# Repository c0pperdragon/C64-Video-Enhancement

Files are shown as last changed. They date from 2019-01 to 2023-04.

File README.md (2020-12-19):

# C64 Video Enhancement

FPGA based modification board for the Commodore 64 computer to produce YPbPr or RGB video output.

The C64 is the most iconic device of the 8-bit computer era and there is a huge library of
software and hardware modifications available.
Nevertheless the video output quality is inherently poor by modern standards, even with the use
of the s-video option. This is specially true with LCD flat screens that amplify the 
visual artifacts even more.

The biggest problem here is the fact, that the VIC-II video chip directly creates a
chrominance signal in the weird and strange way that is necessary for use with
analog television systems. It is then basically impossible to truly convert it back to 
any form of RGB or other component signal (and I tried really, really hard).
And even the luminance signal of the VIC-II is far from perfect and carries a lot of
noise from various sources.

So the way to go was then to bypass the chrominance/luminance signal generation of the VIC-II
and make a solution that computes a YPbPr signal directly from the digital information available
inside the computer. 
As it turns out, it is enough to passively listen to just about 22 pins of the VIC-II to figure out what 
video signal it actually intends to generate. Using the information from these pins and some
logic implemented in an FPGA, a pixel-perfect replication of the video image can be generated.

## Hardware

This mod evolved from a previous version that uses my generic 
[A-Video board](https://github.com/c0pperdragon/A-VideoBoard/tree/master/c64mod). 
It fixes the main
shortcomings of this version, as it was a very ugly install and it needed big holes in the case
for the three RCA plugs. It is compatible with the VIC-II adapter board and the firmware.
This board now is designed to replace the RF modulator and use the existing holes in the 
case. No need to modify the outside of the C64 in any way.

The mod set consists of two main parts:  
* VIC-II adapter
    This is installed between the existing VIC-II and its socket and sniffs all relevant
	signals and translates them to 3.3V logic levels for use by the FPGA.
* FPGA board
    This is connected via a ribbon cable to the adapter to receive the signal stream and
	provide a YPbPr output signal on a 4-pin TRRS jack. 
	Additionally this board carries the necessary electronics to take over the functions 
	of the removed RF modulator to amplify the composite and s-video signals (so the original A/V-jack 
	is still functional).
	
Installation on a 'short' main board	
	
## Compatibility

The mod is intended to eventually support all revisions of the C64: PAL and NTSC, 
long boards and short boards and 5V or 12V supply voltage.
The hardware is already compatible (tested with a long 12V-board and a short 5V-board).
but for some variants of the VIC-II (specifically the 6567R56A that was used in the very
first devices) you may need to update the firmware to the latest version.
The mod boards as sold by videogamesperfection.com have the firmware version 2.6 which already
works with most variants of the VIC. 

To support the 6567R56A chip, the mod additionally needs to be jumpered because it can not auto-detect
this specific variant on its own: You need to connect pin 5 of the JTAG header to ground. This can fairly easily be done by
connecting it to pin 2 of this header.

## Video output

The mod board generates a YPbPr signal which can be switched to one of three modes using the onboard slider switch
(right to left, when looking at the switch):
* 240p/288p progressive 60Hz/50Hz
* 480p/576p progressive 60Hz/50Hz using scanline doubling
* 480p/576p progressive 60Hz/50Hz with visual scanline effect

The signal is provided on a 4-pin TRRS-jack. The order of signals (tip to sleve) is as follows:  Y, Pb, Pr, GND.
This assignment seems to be a kind of standard, but you can use any breakout cable that converts TRRS to 3 RCA 
jacks, as long as the common GND is located at the sleeve.

Use the three-state switch at the back to select the video mode. The 240p/288p mode is not supported by all TVs and will
probably create some de-interlacing artefacts. On the other hand, this mode is perfect to feed into a dedicated
upscaler that can handle it (the famous 'Framemeister' or the 'OSSC' come to mind).
The 480p/576p modes are best used with TVs and give quite a good picture already without any additional upscaler.

Output mode with visual scanline effect	

## Installation instructions

### Adapter board

* Remove the VIC-II and put the adapter board into the socket. The correct orientation for the
adapter is such that the ribbon cable either extends to the right or to the top (depending on your main board).
On some main boards, this could require to either relocate some 
passives or to insert an additional IC-socket to rise the adapter above these passives. 
* Put the VIC-II into the adapter. Make sure to put it in the original orientation.
* I have found that some boards have such a low-quality IC socket that it will not hold the adapter board tightly enough. 
If this is the case, you should replace it with a precision IC socket.
 
### Test the FPGA board (optional)

Before de-soldering the RF modulator, you can test the function of the main mod board. For this, temporarily connect 
one of GND3,GND4,GND5 somewhere to the C64 GND and the rightmost hole of RFCON2 to +5V. Connect the ribbon cable from the
adapter to the FPGA board. The TRRS plug should then already output a proper YPbPr signal.

### Install the FPGA board permanently

* Remove the RF modulator and remove all the solder from the pin holes.
* Install both 4-pin headers in the mainboard, pointing upwards. These pins will later go into the FPGA board to provide power
and to carry the analog signals in and out (to replicate the functionality of the RF modulator).
* Check into which holes in the FPGA board these pins will go. For installation on a "long" main board, these are the
8 holes at the edge, for a "short" main board, use the other set of holes.
* Temporarily stick the FPGA board onto the pins and use it as a means to align the remaining pins correctly to the main board
(either two pins on each side if installed on a 'long' board or only two pins at the back if installed on a 'short' board) 
and solder them to the main board, also pointing upwards. 
These pins are needed to connect the GND as well as to provide the correct vertical spacing.
* Align the FPGA board vertically to the holes in the computer case and solder all pins. For standard pins this
normally means to rise the FPGA board all the way up to the very tip of these pins. 
* If your VIC-II uses the higher voltage (all 6xxx - variants), you need to short the JPLUM1 solder bridge. 
* Connect the 20-pin ribbon cable to the FPGA board.

### Cabling

The 4-pin TRRS connector provides the YPbPr signal, and this can be connected to a TV or upscaler using different cabling options:
* A breakout adapter with a TRRS jack and 3 female RCA jacks. With this a standard YPbPr cable with male plugs can be attached.
* A cable with a TRRS jack and 3 male RCA plugs. This can be plugged directly into the YPbPr input on a TV.
* Some TVs also use a TRRS jack to input YPbPr, probably to safe cost and space. There it is possible to directly use a cable 
with two TRRS plugs on both sides (given that the TV uses the same pin assignment: Tip=Y, Ring 1=Pb, Ring 2=Pr, Sleeve=GND).

## Create your own kit
Everything to create the RF replacement board as well as the VIC adapter board (see the 
[A-Video board](https://github.com/c0pperdragon/A-VideoBoard/tree/master/c64mod)
repository) is completely open source and free to use for any purpose. 

Most parts are pretty standard, only the TRRS connector and the three-way switch are probably not that easy to source with
every electronics retailer.
For your convenience, I have set up a 
[BOM](doc/fpgaboard_bom.ods)
and a project parts list at 
[mouser](https://www.mouser.com/ProjectManager/ProjectDetail.aspx?AccessID=9f8979b031)
that contains everything besides the TRRS jack. For this jack you can use a "Cliff FC68125" with is available at 
several retailers or another part with the same footprint. 
For my original design I myself used an 
[unbranded part from a local retailer](https://www.conrad.at/de/p/conrad-components-klinken-steckverbinder-3-5-mm-buchse-einbau-horizontal-polzahl-4-stereo-schwarz-1-st-718732.html)
which did meet all my requirements and was pretty cheap as well.

Hint for assembling: The holes denoted GND1 - GND5 should not be populated with pin headers during assembly. It is intended that
pin headers that are installed into the C64 main board will stick up through the holes and are soldered as last step
of the installation.
Hint for testing: After the board is assembled and before installing it into the computer, you can already upload
a test pattern generator to the FPGA (available as binary release in the 
[A-Video project](https://github.com/c0pperdragon/A-VideoBoard/releases). 
Do this with a USB-Blaster connected to the JTAG headers. You also must provide 5V-9V on the power pin
(the rightmost hole of RFCON2 - as seen from the edge of the board) and 0V to any of GND3, GND4, GND5.  
The test pattern should show some fancy colors and three gradients to test each of the three signal components.
If the gradients look uneven or have less than 32 different steps each, you probably have some soldering 
problems in the resistor networks.

## Color palette
I have chosen very bright colors for the video output, to give the picture a fresher look. 
Especially "Mayhem in Monsterland" makes much more sense this way ;-)
I know that these saturated colors may not be to everybodies taste. If you want to reduce the color
saturation as a whole, you can replace the resistors R18 and R19 with lower values. 75 Ohm works fine, or
68 Ohm for even lower saturation. If you don't want to desolder these small parts, you could as
well solder an additional 150 Ohm right on top of each of the existing R18 and R19 (this also results
in 75 Ohm total). 

Beginning with firmware version 2.0, you have the possibility to freely choose a color palette that
suits your taste. It is even possible to reporgram the color signals to produce RGsB or RGB signals instead
of YPbPr. When you choose to disable sync, you need to get the sync signal from the original A/V port instead.
In this case it is even possible to build an adapter cable that joins the A/V signals and the RGB signals
together to a single SCART connector.

When you want to use a color palette according to the "colodore" algorithm, you can use Hojo-Norem's
[palette tuning program](https://github.com/Hojo-Norem/c0pperdragon-VIC-II-Palette-editor). 

## Details on color signal reprogramming
Beginning with firmware 2.0, the mod uses a set of 256 16-bit registers to hold the palette information.
These registers can be reprogrammed directly from the C64 and stored persistenly on the FPGA chip.
#### Unlock the registers
Before you can change the register contents, you need to write a value of 137 to memory address 53311.
Then switch the output mode switch to a different mode and back again (back is optional). This sequence is 
necessary to prevent untrusted code to modify the settings. This could a be a special concern on demo competitions.
#### Write into registers
For writing a 16-bit value, you need to first write the low byte into address 53308 and the high byte
into address 53309. Then write the target register number into address 53310. You can store the same value
into multiple registers by writing additional register numbers into 53310 without changing the data each time.
Note that it is not possible to read out any register contents. 
#### Store permanently
When you have changed the registers to your liking, you can store this permanently by writing the value 138
to address 53311. During storing this will also cause some random pixels to appear on the screen for a short time. 
#### Meaning of the registers
The registers can be thought of to form a 16x16 matrix (stored line by line), where each cell specifies the exact color
that needs to be produced when the computer wants to display one of its 16 colors, with the consideration
of which color has been displayed in the line directly above. 

If you do not want to simulate PAL color blending, all rows in the matrix will hold the same value. 
There it does not matter for the current line which color has been displayed above. 

If you want to do color blending, you can cook up any coloring blending 
scheme you want. The register accessed is always defined by currentcolor * 16 + colorabove. 

Each register contains 3 5-bit numbers that specifiy the analog signal levels to be sent on the signal outputs.

| Bits  | Signal |
| ----- | --- |
| 0-4 | Pr |
| 5-9 | Pb |
| 10-14 | Y |
| 15 | unused |

#### Disabling sync 
Bit 15 of register 0 has a special function, as it can be used to suppress the sync signal.
Writing a 1 into this bit will turn off sync on the Y line, whenever the 240p/288p output mode is selected.
In this mode, the luminousity line of the original A/V connector can be used to get the sync signal from
instead. 

## Pixel clock generation

Some C64s - especially the very first models - have a very bad clock circuit that generates an unstable and shaky pixel clock. 
This may lead to all sorts of stability problems, including the component mod showing sparkly pixels or worse effects. 
Because of this, I have added a hidden feature into the FPGA board that generates a stable clock signal you can
use instead. For more details on how to wire this all up, you can check the various issue threads on this topic (but be aware that
this is getting very technical very fast).

## Contact
For technical questions and also to share your experience with this modification, please
use the issue tracking system of github. 

If you really insist on donating money, please feel free to send any amount to my paypal account: 
reinhard.grafl (at) aon.at

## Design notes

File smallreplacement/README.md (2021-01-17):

# Small RF Replacement

I made a smaller variant of the RF replacement board that can be used in C128 machines as well 
as in the C64C. By not supporting the "long" C64 boards with their 12V VIC, this FPGA board could be made
as small as the smaller variant of the RF modulator and this should now also fit where the original
board was too large.

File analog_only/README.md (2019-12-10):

# C64 Video Enhancement, Analog Only

The analog circuit that was just meant as a simple replacement to take over
the function of the RF modulator to keep the A/V port somehow functional,
seems to be remarkably good in its own right.
So for users that just want a cheap solution to improve the original
video signals (luma,chroma,composite), this board may be a viable option.

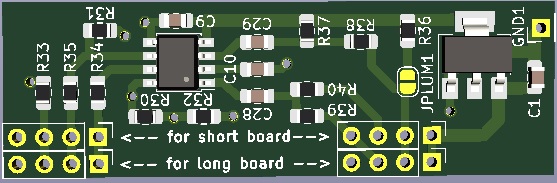
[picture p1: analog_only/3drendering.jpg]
3D rendering of the board


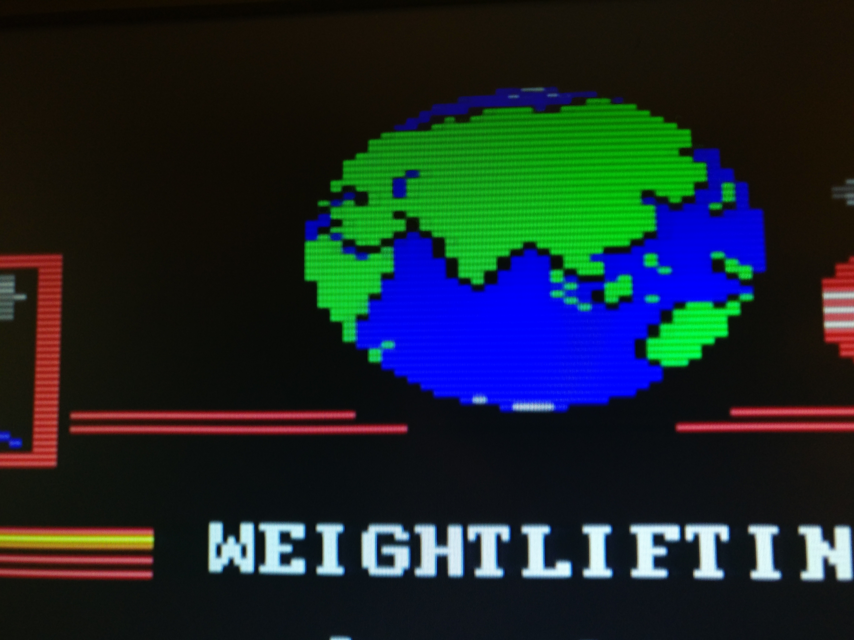
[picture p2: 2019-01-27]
doc/worldgames.jpg

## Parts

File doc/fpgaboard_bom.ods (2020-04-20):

Manufacturer | Manufacturer Number | Designator | Qty | Description | Case | SMD/ TH | PCB side | Comments
Intel | 10M02SCE144C8G | U2 | 1 | FPGA - Field Programmable Gate Array, | 144EQFP | SMD | Top | When hand-soldering: Solder center pad from bottom side
Texas Instruments | THS7316DR | AMP1,AMP2 | 2 | Video Amplifiers 3-Ch HDTV Video Amp | SOIC-8 | SMD | Top
Texas Instruments | LM1117IMPX-3.3/NOPB | REG1,REG2 | 2 | LDO Voltage Regulators 800MA LDO LINEAR REG | SOT-223-4 | SMD | Top
IQD Frequency Products | LFSPXO024957Reel | OSC1 | 1 | Standard Clock Oscillators 25MHz 3.3V 50ppm -40C +85C | 5 mm x 3.2 mm | SMD | Top
NKK Switches | SS14MDH2 | SW1 | 1 | Slide Switches SP3T ON-ON-ON |  | TH | Top
Cliff | FC68125 | J1 | 1 | TRRS Jack |  | TH | Top
any |  | L1,L2,L3 | 3 | Fixed inductors 10uH, 20% | 2012 | SMD | Top
any |  | C8 | 1 | Aluminium Electrolytic Capacitor 100uF 16V | 6.3 mm diameter | SMD | Top
any |  | C1,C2,C3,C4,C5,C9,C30 | 7 | Ceramic capacitor 10uF, 16V, 20% | 2012 | SMD | Top
any |  | C10,C28,C29 | 3 | Ceramic capacitor 100nF, 16V, 20% | 1608 | SMD | Top
any |  | C6,C7 | 2 | Ceramic capacitor 100nF, 16V, 20% | 1608 | SMD | Top/Bottom | Bottom until Rev.3, Top from Rev.4 on
any |  | C11-C27,C31-C34 | 21 | Ceramic capacitor 100nF, 16V, 20% | 1608 | SMD | Bottom
any |  | R27,R28,R29,R33,R34,R35 | 6 | Thick film resistor, 75 Ohm, 1% | 2012 | SMD | Top
any |  | R17,R18,R19 | 3 | Thick film resistor, 150 Ohm, 1% | 2012 | SMD | Top
any |  | R37,R40 | 2 | Thick film resistor, 330 Ohm, 1% | 2012 | SMD | Top
any |  | R36,R38,R39 | 3 | Thick film resistor, 680 Ohm, 1% | 2012 | SMD | Top
any |  | R2,R7,R12,R31 | 4 | Thick film resistor, 1k Ohm, 1% | 2012 | SMD | Top
any |  | R1 | 1 | Thick film resistor, 1.1k Ohm, 1% | 2012 | SMD | Top
any |  | R3,R8,R13 | 3 | Thick film resistor, 2k Ohm, 1% | 2012 | SMD | Top
any |  | R32 | 1 | Thick film resistor, 2.2k Ohm, 1% | 2012 | SMD | Top
any |  | R30 | 1 | Thick film resistor, 3.3k Ohm, 1% | 2012 | SMD | Top
any |  | R4,R9,R14 | 3 | Thick film resistor, 4.02k Ohm, 1% | 2012 | SMD | Top
any |  | R5,R10,R15 | 3 | Thick film resistor, 8.06k Ohm, 1% | 2012 | SMD | Top
any |  | R6,R11,R16 | 3 | Thick film resistor, 16k Ohm, 1% | 2012 | SMD | Top
any |  | R20-R26 | 7 | Thick film resistor, 10k Ohm, 1% | 2012 | SMD | Top
any |  | GPIO1 | 1 | Standard pin header, 2x10 pins, 2.54mm , gold plated |  | TH | Top
any |  | JTAG1 | 1 | Standard pin header, 2x5 pins, 2.54mm, gold plated |  | TH | Top

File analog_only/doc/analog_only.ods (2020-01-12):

Manufacturer | Manufacturer Number | Designator | Qty | Description | Case | SMD/ TH | PCB side | Comments
Texas Instruments | THS7316DR | AMP2 | 1 | Video Amplifiers 3-Ch HDTV Video Amp | SOIC-8 | SMD | Top
Texas Instruments | LM1117IMPX-3.3/NOPB | REG2 | 1 | LDO Voltage Regulators 800MA LDO LINEAR REG | SOT-223-4 | SMD | Top
any |  | C1,C9 | 2 | Ceramic capacitor 10uF, 16V, 20% | 2012 | SMD | Top
any |  | C10,C28,C29 | 3 | Ceramic capacitor 100nF, 16V, 20% | 2012 | SMD | Top
any |  | R33,R34,R35 | 3 | Thick film resistor, 75 Ohm, 1% | 2012 | SMD | Top
any |  | R37,R40 | 2 | Thick film resistor, 330 Ohm, 1% | 2012 | SMD | Top
any |  | R36,R38,R39 | 3 | Thick film resistor, 680 Ohm, 1% | 2012 | SMD | Top
any |  | R31 | 1 | Thick film resistor, 1k Ohm, 1% | 2012 | SMD | Top
any |  | R32 | 1 | Thick film resistor, 2.2k Ohm, 1% | 2012 | SMD | Top
any |  | R30 | 1 | Thick film resistor, 3.3k Ohm, 1% | 2012 | SMD | Top

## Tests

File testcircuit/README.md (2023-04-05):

# Test device for the C64 video enhancement mod

In case of a series production of the mod, you probably need some means
to test the mod boards without actually installing them into a real C64.
For this purpose, the necessary input signals can be generated by a 
second FPGA board, programmed to simulate the various VIC signals.
These are fed into the VIC adapter board (via a ZIF socket for example)
which will in turn drive the FPGA board under test to generate the test image.

The provided firmware (TestSignalGenerator.pof) will turn a standard 
C64 video enhanchement board  into a signal generator that uses the GPIO1 port 
and two additional pins as outputs instead of inputs.
Be careful to use such a board only for this test purpose, as
it will cause damage to connect some other signal source to these outputs.

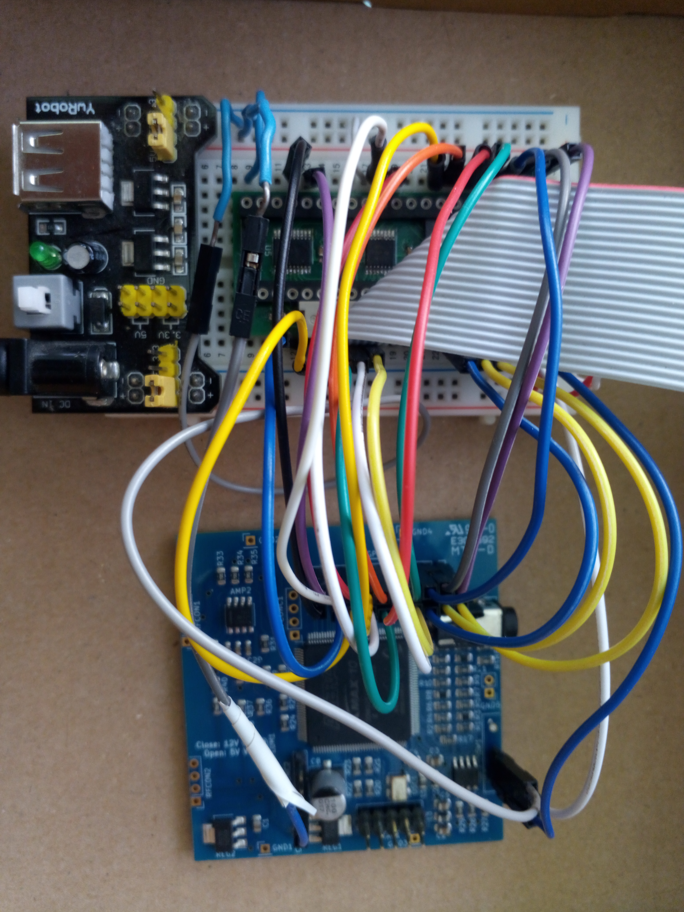
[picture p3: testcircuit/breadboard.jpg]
Experimental setup using a breadboard
	

## Wiring the power 

| Power input  | Signal generator | VIC adapter | VIC-IIe adapter |
| --- | --- | --- | --- |
| +5V | RFCONC2 1 | Pin 40 | Pin 48 |
| GND | SW1 3 | Pin 20 | Pin 24 |

## Wiring up the signal generator outputs to the VIC adapter

| FPGA pin | Signal generator | VIC adapter  | VIC-IIe adapter | VICIIdizer | Signal |
| --- | --- | --- | --- | --- |--- |
| 74 | GPIO1 1 | Pin 1 | Pin 1 | Pin 1 | DB6 |
| 76 | GPIO1 3 | Pin 2 | Pin 2 | Pin 2 | DB5 |
| 78 | GPIO1 5 | Pin 3 | Pin 3 | Pin 3 | DB4 |
| 80 | GPIO1 7 | Pin 4 | Pin 4 | Pin 4 | DB3 |
| 87 | GPIO1 9 | Pin 5 | Pin 5 | Pin 5 | DB2 |
| 91 | GPIO1 11 | Pin 6 | Pin 6 | Pin 6 | DB1 |
| 97 | GPIO1 13 | Pin 7 | Pin 7 | Pin 7 | DB0 |
| 99 | GPIO1 15 | Pin 10 | Pin 13 | Pin 10 | CS |
| 101 | GPIO1 17 | Pin 11 | Pin 14 | Pin 11 | RW |
| - | GND | Pin 12 | Pin 10 | - | BA (unused) |
| 105 | GPIO1 19 | Pin 16 | Pin 12 | Pin 16 | AEC |
| 106 | GPIO1 20 | Pin 17 | Pin 18 | Pin 22 | PHI0/CLK |
| 103 | GPIO1 18 | Pin 24 | Pin 32 | Pin 24 | A0 |
| 100 | GPIO1 16 | Pin 25 | Pin 33 | Pin 25 | A1 |
| 98 | GPIO1 14 | Pin 26 | Pin 34 | Pin 26 | A2 |
| 92 | GPIO1 12 | Pin 27 | Pin 35 | Pin 27 | A3 |
| 88 | GPIO1 10 | Pin 28 | Pin 36 | Pin 28 | A4 |
| 81 | GPIO1 8 | Pin 29 | Pin 37 | Pin 29 | A5 |
| 79 | GPIO1 6 | Pin 35 | Pin 43 | Pin 35 | DB11 |
| 77 | GPIO1 4 | Pin 36 | Pin 44 | Pin 36 | DB10 |
| 75 | GPIO1 2 | Pin 37 | Pin 45 | Pin 37 | DB9 |
| 39 | SW1 1 | Pin 38 | Pin 46 | Pin 38 | DB8 |
| 40 | SW1 2 | Pin 39 | Pin 47 | Pin 39 | DB7 |
| 70 | R0 -> SW1 4 | - | - | Pin 21 | SUBCARRIER  |

_(Most of the pins on both adapters are in the same location relative to pin 1, only the five pins 10-18 are in different locations)_

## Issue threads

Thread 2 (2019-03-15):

Production progress and delivery

c0pperdragon, 2019-03-15:
To keep everybody informed about the situation of my production efforts, I will regularly update this thread.

As you probably guessed, I did not expect such a demand and I did not even have the neccessary parts ready. Of course I now ordered enough to produce 10 kits, and this delivery should arrive in the next days. In the meantime I did scrape together my last pieces and could create just 1 VIC adapter board (which is basically half a kit).

A collegue agreed to let me use his reflow oven and solder paste to speed up a small part of the assembly, namely the underside of the FPGA board. For the rest I still need to manually solder everything. Until we can do that (the solder paste stencil may be a bit tricky to make), I will concentrate on making the adapter boards. So I will not get a complete kit together before at least two weeks or so.

Anyway whenever I have complete kits, I will send them to you in order of payment.
I will send out individual mails notifying you about your position on the list.

Adapter boards: 1  FPGA boards: 0

c0pperdragon, 2019-03-20:
Disaster: My main C64 (a 1986 breadbox) just went to a black screen. This leaves me with only a C64C which I had turned into a NTSC machine for use of making the firmware NTSC compatible.
Anyway this does not hinder me to create and test the actual hardware for the mod, but I can not improve on the firmware features for PAL right now.  With some luck it is a simple fix (the PLA being the first suspect), but I will surely need replacement parts.
Anyway, building of the hardware progresses as planned.

Adapter boards: 3  FPGA boards: 0

bodgit, 2019-03-20:
I found this project via [oshpark.com](https://oshpark.com/). I'm interested in one of these, are orders being taken somewhere? Or have I missed the boat?

Also, would this be feasible to adapt to a C128 (for the 40-column output)?

c0pperdragon, 2019-03-21:
Please leave this issue thread for announcements concerning the current production efforts. You can open any number of new issues for questions.

By the way: Production is progressing just find.
Adapter boards: 5 FPGA boards: 0

c0pperdragon, 2019-03-23:
Busy weekend.
Adapter boards: 10 FPGA boards: 0

c0pperdragon, 2019-03-31:
Building the FPGA boards is a bit more time-consuming than the adapter boards. I finished and tested two this weekend.  But I am not satisfied with the firmware yet, as it still has incompatibilities in the border engine, so I can not ship the kits yet. To get this right, I need the replacement part for my C64(PAL).
Adapter boards: 10  FPGA boards: 2  Shipped: 0

that1crzywhtguy, 2019-04-05:
Will there be another preorder? If so where?

c0pperdragon, 2019-04-06:
Bad news is, the replacement part for my C64 (PAL) does not solve the black screen issue. Good news is, I can just put a PAL VIC into my NTSC machine to make it kinda work like PAL, but with a slightly higher frame rate and with a totally screwed choma output. This now allowed me to get the firmware part for the border logic finally right.
Build progresses just fine, and with two more FPGA boards and the newest firmware, I have new 4 complete kits ready for shipping on monday.
The first 4 recipients on my list will receive their tracking code right afterwards.

Adapter boards: 10 FPGA boards: 4 Shipped: 0

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

MagerValp, 2019-04-07:
Iirc, just swap the crystal as well and bridge the jumper and you'll have a complete PAL conversion.

Great to see the progress!

c0pperdragon, 2019-04-15:
After a busy week, I have now shipped 4 more kits. I will send out individual mails with postage tracking codes today at the evening.

This now completes the backlog of all 8 sold kits.
As I have now parts left to build 2 more kits, I can probably sell these also (given, that I don't screw up on this last mile).  As demand is possibly higher than the supply, everyone who wants to get one of these kits can apply for one right in this thread here. Instead of selling to the highest bidder, I will do a small lottery to decide who gets the option to buy one at the previous terms: € 100 including delivery to the EU. €105 for delivery outside.
Application ends on 20.4.2019, 24:00 MEST.

Additionally I have 2 sets of spare PCBs (one for the VIC adapter, one for the FPGA board) left over. If anyone wants to have any of these (or both sets), I would give them away for parts cost + postage (€13 in EU, €18 for outside). No lottery here, these go to the first persons responding.

Adapter boards: 10 FPGA boards: 8 Shipped: 8

Closed 2019-04-22.

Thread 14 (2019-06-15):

Troubleshooting with testpattern

bwack, 2019-06-15:
Hi. Thanks @desaster for recommending to use the test pattern here: https://github.com/c0pperdragon/A-VideoBoard/releases
I can see a pattern on my scope, but not on the TV. It seems to be very slow. Maybe that is it.
The sawtooth sweeps looks fine, so I guess the resistor ladder is ok.

Looking at Y. 100ms/div, 200mV/div
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

Maybe the fpga needs configuring.. ?

desaster, 2019-06-15:
when powering the board, notice that there are two groundplanes, GND and GNDA. GND1 and GND2 are connected to GNDA. I initially made the mistake of trying to power the board with GNDA instead of GND.

bwack, 2019-06-15:
Ok. I did that mistake the first time. Now the board is in the C64. I see I have soldered four grounds except GND5. Not sure what to do. Maybe the crystal is wrong.

bwack, 2019-06-15:
Ouf, I have mounted the crystal wrong..
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

bwack, 2019-06-15:
It was the crystal. Now there is picture :) Thanks for help !

c0pperdragon, 2019-06-16:
Funny thing that the FPGA actually generates a signal without any oscillator at all. It seems that the PLL inside falls back to generating an ultra-low-speed clock (more than 1000 times slower as planned) when not being driven by an external signal.

bwack, 2019-06-23:
Maybe the VCO in the PLL continues without the lock.. or there is a fallback. I tried to figure out by datasheet, but without luck. Just curious anyway :)

Closed 2019-06-17.

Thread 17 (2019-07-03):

Screengarbage and load errors

bwack, 2019-07-03:
When the vic ii is in the adapter, and i use jiffydos or other fastloader the screen fills with symbols and sometimes a load error appear. Same image on both coomponent and svideo. I have checked the socket and it seems fine. Swapped cias no change. I disconnect ribbon cable to the fpga board and no change. Inserting the vic without adapter no problem.

bwack, 2019-07-03:
Ok now i have the issue without the adapter. Ill have to repair my computer before i continue.

bwack, 2019-07-03:
Removed the swinsid ultimate and problem resolved. No idea..

c0pperdragon, 2019-07-04:
The VIC adapter board is designed to only disturb the rest of the system as little as possible. Each signal is sensed with one high-impedance input that should draw less than 1 microampere and has an input capacitance of about 5 picofarad.
But of course when the rest of the system is already on the very edge of stability this tiny difference may actually push it over the edge.

bwack, 2019-07-04:
Yes. Could have been the drop that filled the bucket. Anyway the computer works fine without the Swinsid Ultimate. I dont think the fault is related. I was concerned that maybe flux residu could cause problems on thr 0.5mm pitch pin, but no..

desaster, 2019-07-04:
#18 is probably not related, since you were also having issues with A/V out.

bwack, 2019-07-04:
@desater. Yes, this happened on my computer with and without the vic adapter. No problems after removing the swinsid ultimate.
The early SSU that I have is covered in hot-snot glue. I've heard about glue becoming conductive after a while, but that is just a guess. The glue covers the system bus lines on the SSU board.

DeSater, 2019-07-04:
@bwack I think you mis-tagged

Closed 2019-07-03.

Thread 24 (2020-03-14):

User feedback and experiences (Part II)

c0pperdragon, 2020-03-14:
Please let the community know about your experiences when building/installing/using this mod.
This is a continuation of https://github.com/c0pperdragon/C64-Video-Enhancement/issues/7 .

Icelvlan88, 2020-04-05:
Build an RF replacement and A-video board. All I'm getting after installation is a black screen. Used the C64mod_2_6_1 firmware. Not getting video out of composite either, again just a black screen sometimes it is colour.

c0pperdragon, 2020-04-05:
I'm a bit confused. Did you build a RF replacement board, or an A-Video board?
Or a RF replacment and the 64 adapter (taken from the A-Video board repository).
It would be best to just add some pictures of your installation...

Icelvlan88, 2020-04-05:
I got a bit mixed up at first. So I built the RF replacement. I believe my issue is with the system itself. Before I started everything was working, but now all I get is a black or pink screen. Would it be possible to help me troubleshoot this a bit? Maybe by email is better since it's not really relevant here.
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

c0pperdragon, 2020-04-06:
I would like to keep this issue thread for communication. Emails are so messy, and a public thread is so much better to help others solving their own problems as well.

Now even having your pictures does not really clear up the issue for me. The second pictures seems to show how the desoldered RF modulator is still attached to the board via wires. No mod installed yet. Did this still work, producing a the signals on the A/V port?

The third picture shows the RF replacement board and the adapter board connected together, but not connected to anything else. On first glance, these two boards seem to look OK. I can not quite make out, what this strange socket is you have connected the video output signals to. Some kind of VGA-style connector, maybe?

Anyway I would like to see how you installed the mod into the C64 to give some more educated guess on what is amiss.

But you actually could also do some tests on the mod board alone to check if the FPGA itself and the video output circuit is working (and your monitor setup as well).
This firmware:  https://github.com/c0pperdragon/A-VideoBoard/releases
just generates a 576p test pattern, without using any of the input lines, so it will show an image on all screens that can accept this type of signal (basically all TVs that have a YPbPr input).

c0pperdragon, 2020-04-06:
OK, I had a second look on the third picture and no I see that you had the board installed in the C64 already (seeing some solder residue on the RFCON1 pins) . So I guess this did not work then and you unsoldered it again and then using the original RF modulator it still does not work.

I really hope that you did not damage your C64 in the process. There are two things I could imagine causing damage:
1. Shorting some of the input signals of the adapter board with solder bridges. This would lead to the CPU / RAM / ROM  / VIC being shorted too causing all types of stress and damage.
2. No proper contact between the adapter board and the main board or the adapter board and the VIC. This may lead to bus conflict in the unlikely case that the VIC now longer properly disables the CPU in the relevant situations.

I fear I can not be of great help in troubleshooting a really damaged C64. I just happen to have a damaged machine (a C64C) myself and just can not find out what is the problem there.

Icelvlan88, 2020-04-07:
Looks like I had a bad PLA.

Another questions. Is it possible to add so component and RGB outputs at the same time? If not, is it possible to add a switch that would allow me to switch between both?

Hojo-Norem, 2020-04-07:
You can't output RGB and component at the same time but you can switch between them using the palette editor.  Get the palette just how you like it in component mode, save it to tape or disk, switch to RGsB (or RGBns if you make a sync cable), tweak the settings if needed and then save that to tape or disk.  Whenever you want to switch between RGB and YPbPr all need to do is load the relevant palette file.  You don't even need to load them into the editor first as the palette files can be loaded straight from BASIC.

Icelvlan88, 2020-04-07:
I’m assuming you mean RGBs? Is it TTL or 75ohm sync?

On Apr 7, 2020, at 5:47 AM, Hojo-Norem <notifications@github.com> wrote:

You can't output RGB and component at the same time but you can switch between them using the palette editor. Get the palette just how you like it in component mode, save it to tape or disk, switch to RGsB (or RGBns if you make a sync cable), tweak the settings if needed and then save that to tape or disk. Whenever you want to switch between RGB and YPbPr all need to do is load the relevant palette file. You don't even need to load them into the editor first as the palette files can be loaded straight from BASIC.

—
You are receiving this because you commented.
Reply to this email directly, view it on GitHub<https://github.com/c0pperdragon/C64-Video-Enhancement/issues/24#issuecomment-610288860>, or unsubscribe<https://github.com/notifications/unsubscribe-auth/APCADXJATQ3HXQUQPOWUJOTRLLZBFANCNFSM4LJHVKHA>.

Hojo-Norem, 2020-04-07:
Nope, RGsB, aka RGB with sync on green.  'RGBns' is RGB without sync, which means you have to use the luma signal from the C64's AV port.  TTL or 75ohm sync?  I don't know, I'm not really an expert.  I suppose the sync level is whatever YPbPr uses as that's how c0pperdragon designed it.

Icelvlan88, 2020-04-07:
Might be component sync as well then. I want to try and put a mini din connector instead of a TRRS.

On Apr 7, 2020, at 7:16 AM, Hojo-Norem <notifications@github.com> wrote:

Nope, RGsB, aka RGB with sync on green. 'RGBns' is RGB without sync, which means you have to use the luma signal from the C64's AV port. TTL or 75ohm sync? I don't know, I'm not really an expert. I suppose the sync level is whatever YPbPr uses as that's how c0pperdragon designed it.

—
You are receiving this because you commented.
Reply to this email directly, view it on GitHub<https://github.com/c0pperdragon/C64-Video-Enhancement/issues/24#issuecomment-610327687>, or unsubscribe<https://github.com/notifications/unsubscribe-auth/APCADXKQXDT2QLNNMTSCJYLRLMDRJANCNFSM4LJHVKHA>.

c0pperdragon, 2020-04-07:
The original A/V port provides a luma signal (greyscale with embedded sync pulses) as well as composite video (brightness, color and sync pulses all combined to one signal). You could use either one as a source for sync in the case that you take pure RGB from the mod board.
But this is neither a TTL sync nor a "pure" 75 ohm sync. Whether your monitor can use this as sync input, you really have to try.
Monitors with a SCART input can normally be made to work with that, as the SCART plug carries wires for R, G, B and component video.

Icelvlan88, 2020-04-08:
I'll have to make a custom cable and find out. Are there other features in the works?

rapiqui, 2020-04-12:
Hi!

I'm currently in the process of building one C64 Video Enhancement RGB board.
I have encountered some difficulties (well, I guess that might be normal if you're not too versed on SMD soldering and FPGA, such as ruining an Altera MAX 10 because of bad allignement), but other than that the project seems to advance.
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
c0pperdragon, 2020-06-29:
It seems that the greater part of the FPGA board works, including all of the output circuit.
Guessing from your image I would say that there are at least two bits of the input datapath not working correctly. One is obviously D6, but D0 seems also to have a problem, as well as one of A0 or A1.

The problem may either be on the adapter board or on the FPGA board. Try to probe the signals comming through the connector cable and if they look plausible, try to check continuity and shorts on the FPGA pins themselves.
As you have built this together yourself, you probalby already know the schematics for both boards.
And I assume you have an oscilloscope. Otherweise troubleshooting would be pretty impossible, of course ;-)

lfitzsimmons, 2020-06-30:
Thanks for the quick reply - Yes defo need to follow the Schematics for this one :) I followed D0 all the way to the FPGA- seemed ok but saw some residue and general fluff on the input pins. Cleaning those up got me a little further:
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

Starting to think my IDC connector may be dodgy
unfortunately now Ive broken a leg off the IC socket, pulling it in and out too many times. So will be back when I've got that replaced ....

lfitzsimmons, 2020-07-09:
Hey me again - just to let you know turns out my FPGA had bad soldering all down the GPIO header. Continuity seemed fine but must have looked ok because I was applying pressure to the pins. While the machine was running I pressed down on the pins and saw the picture improve in places so reflowed that side.
 Looking good to me ! Fantastic picture in person through the OSSC.
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

Thanks once again for all your hard work and for replying! Will test a lot and try to provide some feedback.

c0pperdragon, 2020-07-30:
Finally I got myself an RGB CRT monitor. Using the default RGBns palette from Hojo-Norem's software and it looks great now. This monitor accepts the compositve video signal from the A/V port as sync source, so no additional hardware is needed.
Besides a properly soldered connector cable...
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

lyzanxia, 2020-08-19:
Just bought a mod thru videogameperfection. Installed it and have a nice picture, but am picking up noise from somewhere. I see a rolling down banner of noise across the entire screen. I have since disconnected gnd1 (only gnd3+4+5 are connected to gnd), but this did not help. Picture thru the din connector does not experience this rolling noise. Any idea what I could try to fix the noise?

c0pperdragon, 2020-08-19:
On such a "long" board, you should connect GND1, GND2, GND3, GND4  directly with pins down to the main board, so everything is firmly grounded.

When the noise is rolling through the screen this means the noise must come from the power supply (either internal or external), as it is obviously happening at rougly 50Hz.
I would even guess it must be the 12volt rail that is generated internally by the C64 itself from the 9V AC line.

When you have a multimeter try to probe the various pins of REG1 on the mod board to see what voltage is comming in and what the regulator then makes of if. The incomming voltage should be a reasonably stable 9 to 12 volt, while the outgoing voltage should be a rock-soldid 3.3V.

lyzanxia, 2020-08-19:
I measured REG1. Input is 10,27 volt and output is 3.297 volt

c0pperdragon, 2020-08-19:
These voltages sound reasonable. Still, the noise must be comming from somewhere. Do you also happen to have an oscilloscope to again probe the 3.3 volt rail and see what is going on?

Another possibility is the component video circuitry in the TV itself. Do you have any other source for a component video signal to feed into the TV to check if this is working without noise?

lyzanxia, 2020-08-19:
Unfortunately do not own an oscilloscope.
I am feeding the signal direct into a Dell monitor which has component input . Also tried thru a retrotink 2xpro to hdmi with the same results on another monitor.

I follow your idea of ripple from the psu internal/external..but no idea how to proceed..

c0pperdragon, 2020-08-19:
Without an oscilloscope to hunt down the source of the noise, there is not much you can do, I guess.
Maybe borrow a different type PSU (but do not use an original!) from someone or order it from amazon and send it back the next day...

lyzanxia, 2020-08-19:
Thank anyway for the help. I just rebuilt everything on a spare c64 board 250407 rev B. Exactly the same on this other board. So it has to be the psu which has a too high ripple I guess...

lyzanxia, 2020-08-24:
Received the new other “brand” powersupply and picture is now without interference. Crappy aftermarket powersupply I guess..

Closed 2020-08-24.

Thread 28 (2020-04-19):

Analog only board refdes error

TMS2764, 2020-04-19:
The analog board reference designators C10 and C29 are swapped on the PCB. According the the schematics, C10 is for composite pin 2 and C29 is for Luma pin 3. The video enhancement board PCB is ok.

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

c0pperdragon, 2020-04-20:
Good spot!
I have fixed this in the PCB layout and the gerber files as well.

c0pperdragon, 2020-04-20:
As this is the first time anyone seems to have actually built this board, it would be very nice if you could tell me how well this works for you (photographs are highly welcome also).

TMS2764, 2020-04-21:
I think its great. Glad I found this little analog version design of yours. Just what I wanted to replace those rusty RF modulators that just mess up the video signals.

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

I usually use it in S-video mode. Its difficult to capture but the image is super sharp. The moire effects are from the camera capture. There is no such thing when looking at the screen. There are some visible jail bars.

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

Here is a closeup of the text.

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

Here is the same text in composite video. Its not quite as sharp. Furthermore, there are some video artifacts that are visible but difficult to capture on camera.

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

I hope this helps. Thanks for the good work.

Closed 2020-04-21.

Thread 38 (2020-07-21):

Sparkly pixels

IanSB, 2020-07-21:
User aknightin has reported on the stardot forum an issue with sparkly pixels when used with RGBtoHDMI scaler which get worse as the C64 warms up:

>Despite the occasional offset issue I get a rock solid picture for the first few minutes and then some sparkly pixels that get gradually worse the longer the system is left running.

He is using a 6569R1 and this may just be a heatsink issue but I understand the other possibility is that the interface doesn't phase lock it's sample clock with the 1Mhz clock and that can result in uneven pixel sizes for every eighth pixel.

RGBtoHDMI uses a sample clock which is 8x the pixel clock and is phase locked to Hsync.
During initial setup an auto calibration is run to determine which of the 8 sample points within the pixels produces the best results and the calibration info looks like this:

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

As you can see from the above sample points 5 and 6 have errors as that is probably the transition point between pixels so sample points 1 or 2 would be the best option for reliable sampling.
This should cope with some un-evenness in every 8 pixel group as it will result in some more sample points with errors but there will likely still be a few points with zero errors unless the unevenness is severe.

c0pperdragon, 2020-07-21:
To best test the hypothesis that there is a significant difference in output pixel width, you could use an oscilloscope and check which video signal a regular on-off pattern would produce. Using the regular palette, just write a series of " letters (quotation marks) in white on the C64 screen and probe the Y signal. Being the brightest color it is easy to find with the trigger, The pattern will actually alternate every two pixels, but you should still notice if any one pixel has a significantly different length compared to previous seven.

c0pperdragon, 2020-07-21:
Nominally a C64 pixel should have duration of 126.87 nanoseconds. My FPGA internal clock only allows me to emmit intermediate pixel widths of 126,98 ns. So with a perfectly accurate C64 clock, every 8th pixel would be shortened to 126.1 ms. This is surely good enough to find a good middle position for any digitizing purpose.

But the question is of course which clock the C64 really produces, as this will change the calculation.

IanSB, 2020-07-22:
I received a 6569R5 and that has similar issues that aknightin has seen with the R1:
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

I tried the fix suggested in https://github.com/c0pperdragon/C64-Video-Enhancement/issues/36 but that made it worse.
However putting a small capacitor between pins 20 and 21 did fix it. I am currently using 56pF but will be experimenting further.
This seems to be an issue with boards that use the discrete clock circuit instead of an 8701 (Mine is ASSY No.250407 REV A).

c0pperdragon, 2020-07-22:
The discrete clock circuit really seems to be

c0pperdragon, 2020-07-22:
>

c0pperdragon, 2020-07-22:
...the common factor. I have a vague idea what may happen, but I really need some hard facts. Co

c0pperdragon, 2020-07-22:
...ould you do the requested pixel time measurement? I would need precise times for a series of at least 10 color transitions.

IanSB, 2020-07-23:
> Using the regular palette, just write a series of " letters (quotation marks) in white on the C64 screen and probe the Y signal.

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

Ok I did that and measured the successive double pixel widths as follows:
256, 254, 251, 255, 256, 253, 253, 253, 256, 252, 253, 255, 257, 253, 253, 253, 257, 252 (all ns)

Also aknightin has confirmed that he is seeing the same problem as I do with the R5 chip which is actually one pixel shift of the whole line like my example above and not sparkly pixels as he originally indicated.
Also his problem is fixed with 100pF across pins 20 & 21 as well.

c0pperdragon, 2020-07-23:
So this measurement show a very good PAL signal with pretty perfect timing.
But was this actually in the situation where the computer is having the startup-problem? Because I am especially interrested in the faulty conditionl

I really want to get to the bottom of the real problem, because others may have the same issue as well. Just fitting in the capacitor as a miracle fix is a bit unsatisfying. The orignal problem where this capacitor really makes sense, is when the clock signal to the FPGA board has substantial jitter (pin 20 on the ribbon cable).

Sorry for all this trouble...

IanSB, 2020-07-23:
Ok here is one startup problem, I am actually getting "sparkly" pixels (pixels flickering on/off due to mis-sampling in RGBtoHDMI) and this shows the following with the """"""""" test.

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

The double pixel cycles are alternating at approx 244ns and 223ns

I can't actually get it to left shift at the moment, even with 2.6 firmware but the above effect is also stable, power off/on and it goes away or comes back so probably the same thing.

c0pperdragon, 2020-07-23:
Wow!  This measurement is phantastic!  It clearly shows that the machine runs with a CPU clock of about 0.985 MHz, which is perfectly normal for a PAL machine. But the clock subdivider is set to about 122ns per pixel, which would be correct for NTSC, but now wrecks havoc with both the output pixel durations (every 8th pixel is 158ns long) and probably with the data sample points as well.
The only way this can happen is if the system clock runs fast for a certain time before settling to the correct rate. This probably is indeed the a behaviour of your specific clock circuit.

So, I will try to fix this by changing the firmware to revert to the PAL clock settings even later after power-up if necessary.

c0pperdragon, 2020-07-23:
I have now tried to fix this in the firmware. You can get the latest experimental version (2.8) from https://github.com/c0pperdragon/A-VideoBoard/tree/master/c64mod/experimental

I did my best to not make any errors, and double and tripple checked everything. But I can not test the effect myself, so please give this a try.  This should now solve sparkly pixels, screen corruption and shifted display.

Unluckily when it works for you on your PAL machines, there is no guarantee that I have not messed up the NTSC support. Even more unlucky is the fact that my NTSC machine is broken and I can not test it myself. Maybe I can persuade some user to do the testing....

Icelvlan88, 2020-07-23:
Is it possible to have the switch do RGB 240p/component 240p/component 480p?

Thanks

On Jul 23, 2020, at 1:19 PM, c0pperdragon <notifications@github.com> wrote:

I have now tried to fix this in the firmware. You can get the latest experimental version (2.8) from https://github.com/c0pperdragon/A-VideoBoard/tree/master/c64mod/experimental

I did my best to not make any errors, and double and tripple checked everything. But I can not test the effect myself, so please give this a try. This should now solve sparkly pixels, screen corruption and shifted display.

Unluckily when it works for you on your PAL machines, there is no guarantee that I have not messed up the NTSC support. Even more unlucky is the fact that my NTSC machine is broken and I can not test it myself. Maybe I can persuade some user to do the testing....
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
andriodious, 2020-08-09:
Good day today. C64 is working nicely and I also got my Ace repro build to boot for the first time 👍

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

c0pperdragon, 2020-08-10:
All these experiments show that the clock circuitry is indeed the cause of uneven pixel clock speed. For all normal purposes this would not matter, but for pixel-perfect sampling it does.
The sprite glitches are a different matter and should be fixed in the firmware. Problem is: I don't know how ☹️.

tyristori, 2020-08-10:
I have a problem trying to update the firmware.

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

tyristori, 2020-08-10:
I uploaded C64mod_2_8_beta4.pof to FPGA and now I just get a blank screen. Did I do it properly?
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

tyristori, 2020-08-10:
Nevermind my deleted message. I got the beta4 working now. I'll report back when I've done some testing.

andriodious, 2020-08-11:
As I have a working system now with my R5, I can send you my R1 VIC-II to experiment on on a loan basis if you are interested. It will have it's heatsink fitted as the plaster I used seems to be semi-permanent without the aid of a heat-gun.

I notice there are many 250407 boards on eBay at the moment e.g. [One working board without a VICII (or PLA)](https://www.ebay.co.uk/itm/Vintage-1984-Commodore-C64-ASSY-250407-Board-9-Tested-Good-Condition/224030237676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)

c0pperdragon, 2020-08-11:
I will leave the issue for now, as you both have a R5 chip which seems to work flawlessly together with the mod board when using the early sprite DMA option.
6569R1 chips seem to be a complicated matter - but there are probably only few around from the very early machines, so I wait for the next actual problem before digging further into the matter.

IanSB, 2020-08-11:
>I will leave the issue for now, as you both have a R5 chip which seems to work flawlessly together with the mod board when using the early sprite DMA option

Actually I'm still getting occasional missing lines on sprites with both R1 and R5, maybe 1 or 2 a minute.

>The sprite glitches are a different matter and should be fixed in the firmware. Problem is: I don't know how

Looking at the C64 service manual, there seem to be many "bodge" components that vary RAS/CAS timings to be fitted or altered in value depending on the revision of VIC II installed or even the combination of VIC II + revisions of other chips like the PLA so there probably isn't going to be a universal timing solution.
If you ever do a board update I suggest adding a bank of DIP switches to unused inputs to allow timings to be varied.

As far as the occasional missing lines above, the only option left to try is another delay of 32ns in the same direction as the first one, perhaps by grounding the unused input next to the first one so a bridge across all 3 pins gives 64ns and the two exising bridged pins gives 32ns.

tyristori, 2020-08-12:
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

I removed 47pF capacitor between VIC pins 17 and 20. I put a socket on U31 and I'm feeding the clock signal from FPGA to pin 7.

I watched demos for couple of hours and didn't notice any glitches so for me it's pretty much perfect now. Before with only 47pF capacitor I got occasional glitches and the machine was very unstable. Running firmware 2.8 beta4.

I still get some crashes with demos because of VSP bug. I've ordered a new crystal from RetroTech.

Btw does the trimmer resistor near the Vic do anything with this mod?

c0pperdragon, 2020-08-12:
The trimmer is probably there to fine-tune the master oscillator to exactly 4 times the PAL/NTSC subcarrier frequency. Pixel clock is normally derived from that.
When you are now taking the pixel clock from the FPGA, the mod will no longer be affected by the trimmer adjustment.

ikrananka, 2020-12-16:
Is it critical to use a resistor that is exactly 100 ohm with the pixel clock mod?  The only ones I have readily to hand are some 100 ohm resistors with a 10% tolerance that measure 99 ohm.  I can't imagine that this only make any difference but just want to check before use.

Also, am I correct in assuming that it really doesn't matter if the pixel clock wire connects to the input of FB17 instead of the output?  This is what tyristori has done above but again can't imagine that this makes any practical difference.

c0pperdragon, 2020-12-16:
The exact resistor value is totally irrelevant. I guess you can even leave it away completely without ill effects. But it might reduce potential signal reflection on the cable without slowing down the edge too much. 50 ohms, 200 ohms, will work just as well.

Maybe feeding the signals through FB17 would actually remove some potential signal ringing (which should not be too bad when using the aforementioned resistor anyway). So this may well be viable option here. I would say, just try it. If it works, than its good.

Closed 2020-08-11.

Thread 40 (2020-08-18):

Compatiblity with 6567R56A

c0pperdragon, 2020-08-18:
Hi @laubzega,

As previously discussed,  I have made a first experimental firmware version to support the 6567R56A chips.
These are quite rare and probably no demo directly supports them (different cycles per line and lines per frame). Also there is not much documentation or test programs available.
I think it is good enough if "normal" screen modes and sprites work , without the fancy stuff demo-coders normally use to trick the VIC into all kind of strange behaviour.

You can get this latest firmware from https://github.com/c0pperdragon/A-VideoBoard/tree/master/c64mod/firmware

To actually use the 6567R56A mode, you need to have the pixel clock running at the NTSC frequency (using a normal NTSC computer) and additionally you must pull pin 5 of the JTAG header to ground. Pin 10 and pin 2 of this header already provide ground, so a short jumper wire should work. Obviously you can only attach this jumper when the JTAG programmer is not attached ;-)

laubzega, 2020-08-20:
With the JTAG pins shorted the base image shows up correctly. Also simple demos playing with colors posed no problems (top image is S-Video, bottom - component):

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

However, as I moved to more complex things, it became apparent that not everything is behaving as it should, as this FLI image demonstrates:

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

What you cannot see here is that there is some blinking in the image, suggesting there is some timing component to it. Here is the same  demo working correctly with 6567R8:

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

If you would like me to run some specific test software or demos, just send me a link.

laubzega, 2020-08-20:
One more thing - I have tested two 6767R56A VICs, with identical results.

c0pperdragon, 2020-08-20:
I am actually a bit surprised that it works so well already, as I had only a quity sketchy doc and guesswork.

Before diving deeper into thr FLI topic I would like to ser how sprites behave. Just try a few games and see if everything is actually visible and at the right places.

laubzega, 2020-08-23:
Yup, that was it. With the latest firmware I am no longer seeing issues with Bruce Lee and BoulderDash title screens. Also FLI demo looks correctly.

Ghosting is still there after palette flashing.

c0pperdragon, 2020-08-26:
Oh, my! The FPGA is so totally at its limit that even the slightest changes could cause the VDHL fitter to no longer be able to fit the logic into the device.
So I had to refactor quite some parts to squeeze out a few more LUTs to actually make the changes...

I have included the discussed changes and also fixed the ghosting, at least I hope so, because in my current setup I can not test this...
I also tried to vertically move the display a few lines, in the correct direction, I hope...

Please give the latest firmware (beta7) a try on the  6567R65A. And if this now all looks good, please re-test it on other VICS as well, as I could very well have broken quite some things there...

laubzega, 2020-08-27:
I have a love/hate relationship with logic squeezing. Sometimes it's very rewarding, sometimes it's a major PITA. At least you have a clear migration path to 10M04. Not so with the BeamRacer. :/

Anyway, beta7 works great. I tested both R8 and R56A, no issues observed. Colors align correctly after reprogramming, the vertical shift is no longer there. Games and simple demos I tried worked fine.

Thank you so much for all this work!

c0pperdragon, 2020-08-27:
Thank you very much for all this testing.
I have released 2.9 which should now indeed cover all possible variants of the VIC-II.

I am pretty sure I will not migrate to a larger FPGA. There have been too many boards produced for which I will not give up support. As it seems the feature set is now complete, anyway.

Closed 2020-08-27.

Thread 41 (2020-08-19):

Glitches/Interference with analog only board.

eflopez, 2020-08-19:
I put together a couple of the analog only boards but they both end up with glitchy video. On one, I get good video for about 20-30 seconds and then it starts to have these issues. The other board is no good pretty much straight away. They both exhibit the same artefacts though.

I don't have a lot experience with electronics, so wondering if I've done something wrong, and not sure how to investigate further.

This is for a PAL 250469 (No. 252311 REV.4) shortboard with composite video on a CRT TV.

Any ideas?

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

c0pperdragon, 2020-08-19:
If you are referring to this diagonal stripe of light and the neighbouring vertical strip, I would really have not the slightest idea. But I guess this is just a reflection from your room, door  isn't it?

But I don't know where the rest of the noise comes from. The whole analog signal path of the VIC is pretty bad already, and composite video even more so. The analog video board can not really do much about this. But maybe there is something specificly wrong with your installation. Please make a picture of your install, so I could better guess what is going on.

eflopez, 2020-08-19:
Yep, diagonal line and vertical strip are just a reflection from the window :)

I've uploaded some photos and a video here:
https://drive.google.com/drive/folders/1gSFHNOk5FvQe_4_FEl2io-MgXK0Rk7pV

You can see the noise start at about 14 seconds, before that the output looks quite good.
Since it works well for a bit, my hunch is that as some component warms up, it starts to cause problems.

Please excuse my poor soldering, first time doing SMD.

I did have to substitute the LM1117 which wasn't in stock locally with a TLV1117 which according to the LM1117 datasheet is s drop in replacement could this be the problem?

c0pperdragon, 2020-08-20:
The regulator you are using as very similar specs to my original one. Maybe a very slighly higher drop-out voltage, which could actualy worsen the effect of voltage ripple on the 5V supply line. With a 1.3 drop-out the margin between 5V and 3.3V is already nearly exhausted further degradation will probably show.

The horizontal distance of the vertical noise bands looks like it is caused by some supply voltage ripple of about 100kHz.  This hints at a switching power supply with insufficient ripple suppression.
That the effect starts only after some time may be caused by the PSU heating up.
Do you have an oscillator to probe the 5V line (rightmost pin on your board) to verify this?

Looking at the schematics of your main board, there is the filter capacitor C58 that should already reduce incomming ripple. Maybe this has gone bad already or just is not up to the taks with your PSU. You could try to replace this with a newer and higher-capacitance piece. 470uF could probably improve the matter.

c0pperdragon, 2020-08-20:
oops - of course I meant "oscilloscope", not "oscillator"

eflopez, 2020-08-26:
Hey, I replaced the regulator with the LM1117 and things are working amazingly! Composite looks great too.

Closed 2020-08-26.

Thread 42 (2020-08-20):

Strange stability issue

IanSB, 2020-08-20:
I've had a strange stability issue with my board.

It was working OK yesterday but I started up my C64 today and it was completely dead (power cycled many times)
I'm using the clock from the FPGA and I checked that output and it was missing. I also checked the 3.3v regulators and the crystal oscillator on the FPGA board which were all OK as well as the C64 power rails.
I then tried reprogramming the FPGA and it failed multiple times during programming with "Operation Failed" (The C64 was powered up OK)

I reverted to the normal C64 clock and the C64 booted up OK.
I then tried reprogramming the FPGA and this time it worked and everything is behaving itself at the moment.

One thing that occurred to me is that if the R24 clock out of the FPGA changes frequency with PAL or NTSC would that get into a stability issue as that clock is partly being used to determine if the VIC is PAL or NTSC?
That doesn't explain the inability to program the FPGA though unless the RGBtoHDMI palette detection is screwing up the JTAG interface in this failure mode.

This happened previously about a week ago. At that time I was using a 100R resistor in series with the R24 clock so I removed it and had the R24 clock line directly connected and things worked OK again so I thought it was a faulty connection but it looks like that might have just been coincidence and there is another underlying issue.

I'm running with the normal C64 clock for the time being to see if the problem re-occurs.

Not sure if this is a fault with my board or an issue with the FPGA design. Any ideas?

EDIT:
Just had a failure using the normal C64 clock so I have now reverted to v2.7 which was before the continuous PAL/NTSC switching to see if it happens with that version.

c0pperdragon, 2020-08-20:
Using this pin to send out the pixel clock was a very desperate hack from the very start. It is actually used during the FPGA configuration and is a bidirectional open-drain pin. So it is possible to mess things up when driving this pin in the wrong time. If I understand the doc correctly it is even possible to re-initate configuration later by driving the pin low for a specified minimum time.  That it consistently works on my setup is probably just a lucky coincidence.
The pin should be externally driven high by the R24 pull-up until the FPGA pulls it low to signal configuration completion (also my clock output seems to not cause problems just by itself) Maybe the input circuitry to your VIC draws just too much current to overcome this 10k pull-up and this messes up everthing.
You could try to just use a stronger pull-up instead? Maybe 4k7 alreads does the trick...

c0pperdragon, 2020-08-20:
This again confirms that on FPGA projects, you always should add a few extra IOs for future expansion....

IanSB, 2020-08-20:
I had a failure again with V2.7 and using normal C64 clock (not from R24).
I measured R24 in situ and it was open circuit, I replaced it and re-measured in situ and confirmed it read 10K. It probably became intermittent after attaching the clock cable which maybe disturbed the end cap connection.

I've reverted back to R24 clock and latest firmware and will continue testing.

IanSB, 2020-08-23:
Things have been working OK now for a few days so it looks like it was caused by R24 going open circuit or intermittent.
Just one more thing to be aware of when connecting a pick up cable to one end of R24.

I think this can be closed now.

Closed 2020-08-23.

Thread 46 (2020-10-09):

Mod not working anymore

ei8htthepG, 2020-10-09:
Hi,

my mod isn't working anymore. After I turn the c64 on there is just a weird picture on my BVM and no signal on a second monitor for test cases. The c64 displays a picture via S-Video. The chip on the mod is getting very hot (can't touch it after 5 seconds) shortly after I started the c64. I am a bit afraid. Can I check voltage somewere?

c0pperdragon, 2020-10-09:
If the FPGA (the big square chip) gets hot, this is really a very bad sign. Normally it should not get more then mildly warm even after prolonged use.
You could actually measure the voltages that go into the FPGA on the voltage regulator REG1: Measure voltage between the big tab of this chip and some ground (cartridge slot metal for example). This should have a solid 3.3V.
If the voltage is too low already there is probably a short somewhere or maybe the chip has some internal fault and now burns itself to death.
You could also try to unplug the ribbon cable that goes to the VIC in the case that the short happens there.

In any case I have not much hope that this device can be repaired.
If you got it from videogameperfection, you could ask for a replacement. I don't know about the exact terms but maybe this is covered by warranty...

ei8htthepG, 2020-10-10:
I did some more tests. The FPGA gets hot, when I plug in the ribbon cable. I will contact videogameperfection and hope for warranty. Thx for help.

c0pperdragon, 2020-10-10:
Hmm. Unplugging the ribbon cable actually did help? Maybe the fault is then indeed with the adapter board, so you should also change this to make sure.
If you have some oscilloscope you could actually check the voltages of the signals that come through the cable. Should all be 3.3V signals.

For completeness, could you post a picture of your install?  I would be escpecially interested on the GND connections of the FPGA board - as this chould be a major failure point if not done properly.

Closed 2021-01-09.

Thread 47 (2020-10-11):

A few questions

bodgit, 2020-10-11:
Sorry for the vague title, I realised I had multiple questions :wink:

1. I noticed you've added an FPC/FFC connector to the modulator PCB so it can attach directly to a BeamRacer, (I've got one of these so I'm going to build this new version). I presume from the connector part the cable is 0.5mm pitch and 20 contacts but do you know if the FFC cable should have both sets of contacts on the same side or opposing sides as it means the cable is either pinned 1-1, 2-2, etc. or 1-20, 2-19, etc.
2. With the test pattern firmware, should one of the switch settings produce visible scanlines? I seem to get 576i and 576p but none of them have scanlines that I can see.
3. Building one board as a test circuit to test without having to install every board into a C64 is a really good idea, is it worth trying to reduce the BOM for this? I assume the board doesn't need to be fully populated; it likely needs enough to power the FPGA and connect to its GPIO pins so sections like the resistor network aren't entirely necessary? I'm not sure if the amount of money saved on components is worth the hassle given parts like resistors are fairly cheap.

It's taken me a while to get back to this, (so many projects!), I had trouble getting the JTAG programming to work, I wasn't sure if it was my USB Blaster, or my soldering, or the fact I was using Quartus in a VM with USB passthrough. Turns out I just needed to supply some power to the board, I assumed the JTAG interface did that. Then I found out that my TRRS breakout cable has the Y and Pr connectors swapped which meant I still didn't get a picture when I used the colour of the RCA connectors, only when I hooked up to an oscilloscope was it obvious the sync signals were on the wrong channel.

One suggestion I had is possibly an even simpler test pattern that is just vertical colour bars as that means you only need to capture one scanline between the hsync pulses on a scope to confirm things look correct. I admit I was a bit confused by what I saw on my scope as I didn't know what the test pattern looked like. Now I've seen what the test pattern looks like on a TV it makes more sense.

c0pperdragon, 2020-10-11:
I must say I don't know the orienation of the pins on the BeamRacer. I just included the footprint for the plug on the PCB in the same orientation as for the pin socket. Please write a question in this issue thread - which I have just re-opened - to get a more qualified answer:  the https://github.com/c0pperdragon/C64-Video-Enhancement/issues/33

The test pattern generator only generates 288p (which the TV may show as 576i) or 576p, but no scanlines.

I came up with this test circuit so the manufacturing house who built the latest batch could test their kits.
And you may very well leave out quite some of the parts if it is purely intended to test other boards:  All on the analog side, including REG2, AMP2 and all the passives.    Also AMP1 and the whole video output circuitry there (including all the resistors). Also the TRRS socket and the mode switch are not necessary. In fact you need to  leave away the mode switch in order to have enough outputs to feed to the VIC-II adapter board. It is intended to always test a full set of both the VIC-II adapter together with an FPGA board.

bodgit, 2020-11-16:
Excuse the visible moiré interference, but is the attached photo the expected output for the test pattern?
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

c0pperdragon, 2020-11-16:
This output is not quite right. It should actually show all 16 colors as bars, and the dark blue screen area should be 20 rows high as usual on the C64. And this gray area on the lower portion of the screen is also not correct.
The "c0pperdragon" text looks correct if it is indeed pure white (which is hard to see on this picture).
Maybe something is wrong with the synchronization?  How is this device set up? Is the test signal generator directly connected to the component video mod?  Or is this piped through the BeamRacer?  In this case I assume that the BeamRacer somehow mangles the DRAM refresh pattern.

bodgit, 2020-11-16:
Right, I wasn't sure if I should be getting something that looks similar to a normal C64 screen. The text is indeed white.

The setup is one modulator board programmed with your test generator firmware, wired up to the same VIC adapter board on a breadboard that is then connected to each modulator board in turn running the released 2.9 firmware; I've left the BeamRacer out of the equation for now.

I've tested four modulator boards and they all produced the same output as in the photo, I had a fifth board that was mostly the same but had some artefacts (text was garbled and some pixels on the left border were a different colour) but I think I've tracked that down to a tiny bridge on one of its GPIO pins which I've fixed, (so the test firmware worked in that regard!), I just need to retest that board.

All of the modulator boards ran the standalone test pattern firmware and produced the same output so I think the problem is with either the modulator board running the test firmware or the VIC adapter. I'm fairly sure I wired up the GPIO pins to the VIC adapter correctly but I will doublecheck them again now I know the output is wrong, could this be the cause? The bottom border at least seems to be in the right place but just the wrong colour.

laubzega, 2020-11-16:
Which VIC version is that? Have you tried with a different one? @c0pperdragon, is there a reference image for the test pattern somewhere online?

bodgit, 2020-11-16:
@laubzega There isn't actually a VIC or even a C64 involved at this point. This is using a second modulator board as a signal generator to test the hardware.

c0pperdragon, 2020-11-17:
This miss-aligned frame synchronization hints could be caused by the RAM refresh pattern to not be properly recognized. This RAM refresh is detected by the mod by monitoring the A0 and A1 lines. So I guess these may not be wired up correctly in your testing rig, or the VIC adapter itself  does not properly forward these signals.

bodgit, 2020-11-18:
I tried swapping out the VIC adapter for a different one and I get the same output still so I think that should rule out the VIC adapter as the source of the problem. I traced through the A0 and A1 pins on the VIC adapter to the A1 and A2 input pins on the LVC245 U5 and then the B1 and B2 outputs from that go to the other end of the IDC cable.

I've also confirmed that pins 100 & 103 on the test FPGA are connected to pins 16 & 18 on the GPIO pin header which are the A0 and A1 outputs to the VIC adapter. The A0-A5 pins are mapped 1:1 to GPIO pins, 18, 16, 14, etc. so I can't see how I've got those wrong.

If it's helpful, I can put a scope on the A0 and A1 lines before/after the VIC adapter and see what it's doing.

bodgit, 2020-11-20:
Here's what I grabbed with my scope, capturing A0 and A1 from GPIO pins 14 and 13 between the VIC adapter and the modulator board being tested:

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

I probed the Luma channel too so I can see the vsync pulse and use it to capture a single frame. It looks like there's a "missing" A0 and A1 pulse just after the vsync is observed. Is this what you were talking about?

c0pperdragon, 2020-11-25:
Sorry for the late reply, but I just had no idea which advise I could give you.
Until now, that is.

Quite some time ago, I made the special firmware for signal generation to help the manufacturing house test the mod boards. They programmed firmware 2.6 to the production boards, and they worked fine with the signal generator.
Since then I have made some modifications to the firmware to support other VIC variants as well and this also affects the frame synchronization. I have not re-tested any of the newer firmware versions with the signal generator, so it may very well be that it is now no longer compatible. To check this, just use the firmware 2.6 on the device under test and see how the output looks like. If it is OK then you at least know that the hardware is working correctly (all the soldering and wiring of the FPGA board and the adapter). Then you can re-programm it back to the newest firmware and be quite confident that it is still OK.

bodgit, 2020-11-26:
Last night I thought "what the hell" and installed one of the boards as a quick experiment and it seemed to work fine, (main C64 screen followed by a few `POKE 53280,x`'s) so I think you might be right. I will put 2.6 on one FPGA board and see what happens and report back, but I think because all of the boards behaved consistently under test I think they're probably okay.

bodgit, 2020-11-26:
Your hunch was spot on, with 2.6 flashed on an FGPA board I get this:

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

c0pperdragon, 2020-11-26:
So this looks perfect now. Only this small white vertical line in the upper right part is strange. But maybe this is just a reflection on the screen?

Sorry about the confusion - I really did not think about possible incompatibilities with later firmware versions.
I guess you can use the signal generator anyway also for the 2.9 FPGA firmware. As you now know how this looks, this is good enough to confirm that a given hardware is OK.

bodgit, 2020-11-27:
Ha, yes, I think it's just a reflection of a window behind me but it does look like some pixels. It was a fun debugging exercise and even though I wasn't getting the "correct" picture, it was still enough to show up one board that had a tiny solder bridge on the FPGA GPIO pins so it was very useful in that regard.

With all of that sorted, I tried adding my BeamRacer to the C64 and I can confirm it all works 👍

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

c0pperdragon, 2020-11-27:
Congratulations to sorting this all out now.
I have a small question, though. I see you are using one of my later mod board. I would actually like to know how the new big heatsink area for the voltage regulator REG1 performs. On a long board with its higher voltage, this regulator normally has quite some heat to dissipate. On the previous boards it got quite hot (not too hot to touch, but still). This here now should run much cooler, but I have not actually tried it myself. Maybe you could test this after letting it run for 10 minutes or so?

bodgit, 2020-11-27:
Sure, I can test this out. I'm actually just fitting some heatsinks to the big MOS chips like the VIC and SID so I'll be testing how warm everything gets in general.

bodgit, 2020-11-27:
I've now run it for a while watching a few demos and I don't think the regulator is even as warm as the FPGA, and neither are anywhere near as warm as the VIC gets.

c0pperdragon, 2020-11-28:
Thank you for testing that. Its good to know that this works so well.

Closed 2020-11-28.

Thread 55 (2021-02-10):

artifacts and how to program

a7mag3ddon, 2021-02-10:
HELLO

I have a pal c64 with longboard and im getting artifacts on the screen for a few minutes after turning on and sometimes im missing red from the screen.

On another forum (Video Game Perfection) someone else was getting same artifacts and fixed this with a firmware upgrade so was wondering if theres any instructions for how to flash my board ?

The second question i have, is there a way to see what version of FW is on my board? It was purchased around middle of NOV and fitted around the 4th Dec from VGP.

Thanks

c0pperdragon, 2021-02-10:
There is no direct way to know which firmware is flashed to the board. But if you have it from videogameperfection.com it is surely 2.6.

To upgrade the firmware you need to purchase a small programmer device, the "USB-Blaster", which can be bought fairly cheap.
You also need the "Quartus Prime Lite" software to do the programming from the PC  (free download but quite big).

Which long board revision do you have? The very first ones (with the non-integrated clocking circuit) are known to cause problems like this. The newest firmware works around most of these issues.

a7mag3ddon, 2021-02-11:
I have a usb blaster arriving today and i have the intel fpga software and max10 addon at the ready, my board i thin ends 407 i will dig out some photos of internals and take a look as im not with machine at the moment.

a7mag3ddon, 2021-02-11:
apologies for the delay, the assy no is 250401  art : 251137 Rev C which i assume is a very common PAL machine

Going to flash/program the fpga in 10 mins.. fingers crossed.

a7mag3ddon, 2021-02-11:
Ok all flashed, and put a small sticker on saying FW 2.10 with the date. Hope thats sorted my 2 problems out, lack of RED and artifacting.

c0pperdragon, 2021-02-11:
Guessing from this list of board revisions

http://www.cbmhardware.de/show.php?r=1&id=25/Die%20Platinen%20des%20C64

this seems to be one of the early boards with the multi-chip clock circuit.
This is known to cause problems with the 2.6 firmware. If 2.10 does not already fix this, there would be an additional tweak to use a cleaner clock. As added bonus this often also cures the infamous VSP-bug.

a7mag3ddon, 2021-02-11:
Where is the info on the cleaner clock mod? I will take a look and see if its worth doing.

a7mag3ddon, 2021-02-11:
I think this is what i need ?

https://www.ebay.co.uk/itm/MOS8701-Clock-Chip-Replacement-Commodore-C64-C128-small-size-big-performance-/133504255823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

ikrananka, 2021-02-11:
Isn't your Assy No.250407 and NOT 250401 as you state above?

The 250407 uses an older, more complex, clock circuit compared to later motherboard versions.  The eBay auction you link to is for a replacement of the single clock chip in motherboards later than the 250407, i.e. that part is not compatible with your motherboard.

a7mag3ddon, 2021-02-11:
Damn, what options do i have?

ikrananka, 2021-02-11:
If after upgrading to the latest firmware you're still getting graphical issues then you'll likely need to do the "pixel clock mod".  Check out Issue 53 for this GitHub project where I did it on my 250407 board.

The original post detailing the procedure is here: https://github.com/c0pperdragon/C64-Video-Enhancement/issues/38#issuecomment-663986704

a7mag3ddon, 2021-02-11:
Its all getting a bit complicated now, i need to solder a wire from R24 and connect it to pin 6 of the lifted 8701 ?

ikrananka, 2021-02-11:
There is no 8701 on your revision of the motherboard so that is incorrect.

On the 250407 board you, in effect, need to disconnect pin 7 of the 74LS629N (U31) and connect your new wire to the motherboard where that pin was previously connected to.  If you want to avoid any desoldering then the simplest route is to cut the right-hand leg of FB17 and lift up FB17 to move it out of the way (Note that FB17 is connected to pin 7 of U31 hence why this is an alternative solution).  Then solder a wire from the left side of R24 (see the photos to make sure) to where the right-hand side of FB17 went into the motherboard.  Check out the third photo in this comment : https://github.com/c0pperdragon/C64-Video-Enhancement/issues/38#issuecomment-671067022 to verify the correct locations.

Note that it is recommended that you include a 100ohm resistor in this new connection which you'll see in the photos.

For me, I preferred to retain the FB17 in place and still have it active in case it might still help eliminate a small amount of noise from the signal.  So, I desoldered U31 completely and soldered my new wire to the left-hand side of FB17.

a7mag3ddon, 2021-02-11:
Oh yeah, aorry i confused myself there.

I will try this mod and see if it fixes my lines problem when cold i can cleay see FB17 in thay photo in the other thread.

Do you know what R27 does on this board ,? Do i need it ?

ikrananka, 2021-02-11:
> Do you know what R27 does on this board ,? Do i need it ?

That's something @c0pperdragon will have to answer.

c0pperdragon, 2021-02-12:
This trimmer seems to be used to fine-tune the oscillator. This is necessary to get the exact PAL/NTSC subcarrier frequency. The pixel clock is then derived from this.
When you take the pixel clock from the FPGA, the subcarrier frequency is still used to produce the color signal for the analog A/V port.

Closed 2021-04-23.

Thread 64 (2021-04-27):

C128 support (#2)

c0pperdragon, 2021-04-27:
This is a continuation of https://github.com/c0pperdragon/C64-Video-Enhancement/issues/4

lolof70, 2021-04-28:
Thank you very much for your great support ! Really happy, I will build one for my C64.
Thanks again.

lolof70, 2021-05-07:
After some more testing, I do not know why, but some times the image is stable, sometimes not.
When it's not stable, there is light movement mostly horizontally or lightly in diagonal.
Moving a bit down to up... Like if it was doing this with the back colours. The rest seems stable.
I thought it came from the PSU because the video cable connected from the fpga board to the A-board was very near to the psu in the 128DCR. I turned the cable the other way so it goes on the opposite side of the psu and it changes nothing.
The PSU has been recapped as all the 128DCR....

I read about a 47pf fix or a fix from #38 but I can't find where are the exact infos.

Is it something I could try.

Very strange because it can do this for a moment then stop for some times  then start again....

c0pperdragon, 2021-05-07:
You should also try different output modes. You can switch between 240p/288p and 480p/512p with the mode selector.

lolof70, 2021-05-07:
Different output changed nothing, also tried with OSCC and the result was the same, even amplified.

I can't almost not believe it....

The dcr was plugged  on a 220V power multi block...
I tried powering the C128 alone from another wall plug. No more on multi block....

It's working a lot better. this effect is almost gone... Just time to time but nothing as before when it happened...

Strange. I checked on the normal video din output, this effect are not to see.

c0pperdragon, 2021-05-07:
Could you do some video capture with the PSU that causes the worse picture? I still can not quite visually imagine what you mean.

lolof70, 2021-05-08:
Yes, done

https://youtu.be/xooaiQYsORM

c0pperdragon, 2021-05-08:
So, at least I see that it is no problem on the digital side between the C64 and the mod board. The problem here is some analog noise.

Your experiement with touching was very important. It is absolutely not normal that such minor capacitive changes should cause any noticable difference on the screen. My only conclusion is that there is something faulty with the DAC resistors or the soldering of the FPGA pins. Maybe one of the many legs of the FPGA has no proper contact or some flux residue causes leakage current between pins or something like that.

lolof70, 2021-05-08:
The board was put in a propanol ultra sonic bath. It's very clean.
I will check again the legs from the fpga. Which one are de DAC resistors ?

Also... I build 2 board (I forgot this !!!!).. I will connect the second one and check if it does the same, also with touching...

lolof70, 2021-05-09:
The problem with touching the FPGA is solved.
You were right ! I had 2 pins not well soldered on the FPGA... I missed them when I checked after soldering...

I checked again on my big TV who can do 240P.... Best results is using 240P and with the power cable alone in a 220V plug.
Probably same as before. 480P is always with this noise on big and small TV...

I will try to feed the video on the small TV through HDMI with OSCC and 240P from FPGA....  The small TV is the one I want to use with the 128... If it does as well as on the big TV 240P, I will be happy :-)

c0pperdragon, 2021-05-09:
So, if there is at least one TV that shows the picture perfectly, then the signal is obviously perfect already and no action is needed on part of the YPbPr mod.

lolof70, 2021-05-09:
Yes, the mistake was the 2 pins not soldered on FPGA and a bad combination of TV during the tests....
I played already a lot with it, impressive with the right TV ! Thank you.

mincebert, 2021-07-29:
I've been watching this (and the previous thread) hungrily, in anticipation for my 128DCR...

Does anyone know of someone selling these boards for the 128?  My soldering skills aren't up to something like this, so I was hoping someone would offer them, as per the C64.

Thanks in advance for any solutions!

djcarlin, 2021-07-30:
I too am interested in purchasing a kit, for my C128 - similar to the C64 kit I bought from VGP.  Thanks!

c0pperdragon, 2021-07-31:
As it currently looks, the global semiconductor shortage also hits us hobbyists pretty hard. The FPGA that is the central part of the mod is sold out and may become available again earliest 2022-7 (but no guarantees, of course). Even then I am not sure if I will have the time to take up soldering these FPGA boards anyway.

There may still be another option. The FPGA board from the C64 mod is basically identical to the shrunken-down version for the C128, So If you want to become creative, you could actually order a C64 mod from videogameperfection.com, discard the C64-VIC-adapter (a shame to waste it, but, well...). Then add a C128-VIC-adapter for which parts should still be fairly easy to get.  Fitting the C64-FPGA board into the C128 is probably quite difficult and may require cutting away some shielding metal, but I guess you could do that.
If you want to go that route, I could check if I can get all the parts for the adapter (still have 6 PCBs for that) and build these for a reasonable price.

c0pperdragon, 2021-07-31:
You could actually ask user @bodgit if he has some kits remaining from his batch of 5 he made a few months ago. (https://github.com/c0pperdragon/C64-Video-Enhancement/issues/4).

djcarlin, 2021-08-01:
Ideally, VGP could start carrying the C128 kit once the FPGA is available again in coming years?   Matt @BuckoA511 expressed interest in carrying such a kit here:

https://github.com/c0pperdragon/C64-Video-Enhancement/issues/4#issuecomment-773215229

bodgit, 2021-08-02:
Yes, I do have some spares still. I will email both @mincebert & @djcarlin to the address that is in your profile or commit history.

mincebert, 2021-08-03:
> Yes, I do have some spares still. I will email both @mincebert & @djcarlin to the address that is in your profile or commit history.

Thanks — that's much appreciated!  (I don't think I was showing an email in my profile or if there was another way to contact me, but I think I am now.)

bodgit, 2021-08-04:
> > Yes, I do have some spares still. I will email both @mincebert & @djcarlin to the address that is in your profile or commit history.
>
> Thanks — that's much appreciated! (I don't think I was showing an email in my profile or if there was another way to contact me, but I think I am now.)

You hadn't, but I cloned one of your repos and used the email address you used for commits, it went to rcf@m****.net.

bernouilli, 2021-08-06:
Hello,
I just found the great project and would like to get a kit for my c128.
Does anyone have any kit left?
Regards.

bodgit, 2021-08-07:
I have my last two left now. From the old #4 issue I think @nickgoodmanuk wanted one as well so I'm tagging him as well. If you can let me know your email addresses (I can't see an address in your profile) I will contact you both with details.

bernouilli, 2021-08-07:
That's perfect. Here is my email address : bernouilli92@hotmail.com

nickgoodmanuk, 2021-08-10:
Brilliant ! My email is nick@nickgoodman.plus.com.

Many Thanks.
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
johansmolinski, 2022-09-17:
I'd love a board compatible with my C128DCR as well. Please sign me up if there is a list for that anywhere. :)

bodgit, 2022-09-29:
They're charging between $75-$90 per chip (depending on quantity). They normally would be less than $10. That's quite a markup!

I think they are being produced, but they're being snapped up by volume buyers so there's none spare for people like us who are essentially hobbyists. I think I've purchased as many as 10 in one order, which is nothing really.

johansmolinski, 2022-09-29:
Ok, I had no idea they originally were that cheap. Heck, an FPGA for less than $10?! Wow...

Do you have all other parts for what is needed to build a board that will fit inside a C128DCR?

thepebbler, 2023-04-15:
> They're charging between $75-$90 per chip (depending on quantity). They normally would be less than $10. That's quite a markup!
>
> I think they are being produced, but they're being snapped up by volume buyers so there's none spare for people like us who are essentially hobbyists. I think I've purchased as many as 10 in one order, which is nothing really.

I've just grabbed two C128's (A C128D and a regular C128) , both are broken, but the plan is to get the C128D resurrected and wanted to get a the small board version, but don't have the kit to solder the FPGAs on!

Is anyone planning on doing a batch? I might be able to help source the FPGA if that is the blocker, I can ask in work and get our CEM team (they work with our CEMs making our PCBAs) to see if they can source the FPGA at a reasonable price, and get some at cost.

scorpio-ny, 2023-05-09:
Before I order a PCB, I wanted to check here to see  if anyone has an extra VIC-IIE PCB adapter or an extra assembled VIC II-E adapter they do not need and would be willing to sell? A while ago I had purchased a 64 kit from VGP in which I was saving for when I would get a C128 (finally acquired). Thank you!

johansmolinski, 2023-05-31:
I am offering to trade a fully working C128 PAL with 6581, healthy yellowed, **without** PSU for a full c0pperdragon C128 kit that will fit inside my C128DCR. I can do whatever needed to fit it, if it means cutting things and relocating capacitors or whatnot, as long as the kit is complete. I live in Sweden, so I would prefer to do it within EU, but everything is possible.

c0pperdragon, 2023-05-31:
c0pperdragon here.
Even I don't have any of those boards. But maybe you would be interested in
my follow-up product. It solves the same issue in a new way using a small
mod board and an external RGBtoHDMI. See https://github.com/c0pperdragon
for the C64 variant.
If there is demand, I could also make a C128 version.

Johan Smolinski ***@***.***> schrieb am Mi., 31. Mai 2023,
08:07:

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

johansmolinski, 2023-05-31:
Thanks for prompt reply! Your link is to your profile. Which of the repositories are you referring to? And will it be usable for hooking up the C128 to a 15 kHz CRT on RGB? That's all I care about. :)

c0pperdragon, 2023-05-31:
it is the wiki section of github.io  .
and currently the solution is for HDMI upscaling.
but maybe i can dream up some DIY circuit to get RGB again.

Johan Smolinski ***@***.***> schrieb am Mi., 31. Mai 2023,
10:08:

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

rasivert, 2023-05-31:
> I could also make a C128 version.

Very much interested in a C128 version!

johansmolinski, 2023-05-31:
Would the RGB2HDMI be able to output 15 kHz, like "direct video" on MiSTer? If so, you could probably use a cheap HDMI to VGA adapter to get good 15 kHz RGB that way.

Still I don't find the information you are referring to. I would really appreciate a direkt link, please. :)

c0pperdragon, 2023-05-31:
https://github.com/c0pperdragon/c0pperdragon.github.io/wiki/VIC-II-dizer

c0pperdragon, 2023-05-31:
I hope, I do not give away confident information, but videogameperfection.com seems to be in the process to stocking up on the C64 variant of the mod.
Looking at the pictures of the C128DCR motherboard, at least the FPGA half of the mod may actually just fit.
Maybe someone has/can make a VIC-IIe pickup board.

In case you can not get a suitable pickup board, you can even try a super-badass hack, I just came up with: Instead of putting a pickup-board between the VIC and its socket (which will only work when you have the correct board), you could instead piggy-pack the C64 pickup board onto the VIC. Most signals are at the same place, so you only need to cut away 6 of the pins and re-reoute these signals . If you want to go that way, I can give more detailed instructions.

c0pperdragon, 2023-06-01:
I created a new thread for this topic, at this here is already much too long again:
https://github.com/c0pperdragon/C64-Video-Enhancement/issues/89

Closed 2023-06-01.

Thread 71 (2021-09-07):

No C64 screen, only test palette output

Syntec1, 2021-09-07:
Hi,

I feel kinda stupid as I get the feeling I'm missing something here.
So the issue is that the Vic2 board has been connected and everything to the FPGA board which I assembled and is outputting the default palette colors.
I have clear output on the Svideo out and programmed the FPGA with the C64mod file.
As I can see the Vic2 board is outputting signals to the FPGA board so I'm guessing that I did something wrong with writing the software to the MAX10 as that is new for me?
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

Can someone assist me for troubleshooting the issue?

Thanks!

c0pperdragon, 2021-09-08:
You have programmed the test firmware to the board, which is intended to check the only the video output output circuitry (which seems to work perfectly).
What you now need instead is the actual firmware for the VIC2 emulation which you can get here: https://github.com/c0pperdragon/C64-Video-Enhancement/releases

Syntec1, 2021-09-08:
I have installed the 2.10 firmware and I get an input signal with only a black screen.
I double checked the svideo output and there I get a c64 screen.
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
I have a 250407 board and I read a lot about the clock issue, do I need to do this or is there another fault?
The only thing I just noticed is that I installed for the 3 resistors (R5,R10 and R15) that are 8K, the 8K2 resistors, will that have a to big of an impact on the signal or as the output circuit is working should this be okayish?
Just want to eliminate anything that could cause the issue. (For some reason I got 8K2 marked as 8K after measuring and checking)

c0pperdragon, 2021-09-08:
When the test signal did work fine you have no problems with any of the resistors of the signal output circuitry.
The problem is very likely that the signals (at least the clock) from the VIC2 do not reach the FPGA. If you have an oscilloscope, probe the various signal paths the check if there is activity. Otherwise do very close visual inspection of all the pins. Especially the input pins of the FPGA can cause trouble with solder bridges.

Syntec1, 2021-09-14:
Excuse me for the delay, my VicII 6569 decided to quit on me and I replaced it with a 8565 R2 and made a mod in the 12V pin13 line so it's now 5V and had the oscilloscope ready then to my surprise your board started to work.
I also changed your board to 5V Vic instead of 12V just in case.

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

The edges and text I assume will be the pixel clock issue were I need to do the mod right?
Just to check with you

Syntec1, 2021-09-15:
I had a delay in testing as my original VicII suddenly died on me 6569.
I decided to replace it with a 8565 R3 and mod the 12v voltage line to 5V, this works, I changed the FPGA board also from 12V to 5V Vic just in case.
After that modification I was ready with the oscilloscope to start measuring but the board started to work.
Noticed I needed to do the pixel clock modification which I did and I have an almost perfect picture except for a bar moving slowly upwards.
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

You see the distortion on the edge which is moving slowly upwards, any ideas were that can come from?

c0pperdragon, 2021-09-15:
When the effects moves slowly up or down the screen, this is a very good indicator that it has something to do with the 50Hz power grid frequency. The issue can either be the C64s (including the mod board) or he Monitor. Do you have some means to check how it looks on a different monitor/TV?
And if this issue is independent of the monitor, how does it compare with using the original s-video signal?

Syntec1, 2021-09-17:
It was the upscaler I was using, now connected to the RGBtoHDMI it is perfect.
Thanks for the support, very fun project to build from start to finish!

Closed 2021-09-24.

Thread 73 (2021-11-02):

Need help with FPGA Mod + external RGB2HDMI

lolof70, 2021-11-02:
Hi,

I do not know if I have to post this here or to the rgb2hdmi page..
I am trying here. I just added the external RGB2HDMI to the FPGA mod in a C64.
FPGA mod is working perfectly...
I have problem with the RGB2HDMI mod :-(
See the pictures. Colours are not good. I have the last version on the FPGA board. So I did not had to programm the C64 palette.. I put a bridge on the pin 9&10 from the fpga jtag connector. The switch is on the right side (facing the C64).
My cable seems to be OK, I checked it again now..

I am afraid it could be a problem with the analog board issue 3... I do not know where to look.

All parts of the analog Board are from Mouser except the MAX5259+ (not available. Found @ ebay china
D1 is not the one from the bom, not available. I took another one

https://www.mouser.de/api/CrossDomain/SetContext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

Could someone help me. Thank you.

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

c0pperdragon, 2021-11-02:
When the mod board gives correct colors in normal operation (no jumper), then it is very unlikely that this is the problem.
So the issue is either with the cabling (if you are lucky) or with the analog board (unlucky) or it is just a matter of correctly calibrating the input voltage levels (extremely lucky).
Try playing with the rgb2hdmi settings first and see if you can make the board discriminate 3 different input levels on each of the signal components (Y, Pb, Pr). The sync already is detected perfectly.
I don't remember how to use the settings menu of the RGB2HDMI but after pressing the button, you should be able to guess your way through the menu.

lolof70, 2021-11-02:
It's like it's missing red and blue colours... I saw yellow, black, braun,....
I re-checked the cable. I do not see a mistake...
I changed the only parts coming from ebay china with another from the lot I bought, just in case... Same result.
I went in Menu and tried to change what I could, like contarst etc....  Dors not help.
I also connect all on another monitor. Same....

How do I calibrate the output voltage ? I did another board, digital for C128 and this one worked directly with default setting on the same monitor...

lolof70, 2021-11-02:
Just found an error I did on the analog board......
Maybe it's the problem.

R1 should be 470 ohm... I do not know why, I put one of 100 ohm....

lolof70, 2021-11-03:
Tried with R1 470 Ohm on the analog board. No difference...

A last question, on my FPGA board, I replace R18 and R19 by 75 Ohm, should I put the original value one ?
Can this be a problem ?

I also put my cable connection here just in case......  If I well understood the wiki, this should be correctly connected...

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

c0pperdragon, 2021-11-03:
Yes, this would definitely make a difference. With this lower-value resistors the output levels for Pb ad Pr would be muhc lower. This would lead to less saturated colors when used with a normal YPbPr-enabled TV. But due to the the way the RGB2HDMI reads the analog signals, whis would very likely cause the input to be incorrectly interpreted when using the default settings.
So either replace the resistors again or reconfigure the input voltage levels for the red and blue lines using the RGB2HDMI's settings menu.

c0pperdragon, 2021-11-03:
Have a look at
https://github.com/hoglet67/RGBtoHDMI/wiki/Reference-Guide
in the section Sampling Menu (6 BIT RGB analog inputs)
This is where you can reconfigure the analog voltage levels.

lolof70, 2021-11-03:
Problem fixed...

Yes, it was only the 2 resistor I replaced. I put the original value back on the board and now, all is working perfectly !

Thank you for all.

Closed 2021-11-04.

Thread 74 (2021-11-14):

C64RGB RGBns Scart support

rapiqui, 2021-11-14:
Hi,

I have installed a C64RGB mod on a C64C with success, being able to get a wonderful and crisp image from the TRSS YPbPr output on a LCD TV with composite video.

The fact is that I wanted to get rid of the TRSS connector and went ahead building a custom din8 connector on the C64 motherboard, getting only GND, Audio and Luma from the board, and freeing the rest of connections to accomodate R,G and B channels from the C64RGB mod.

Having tried the colodore palette (RGBns) and the original RGBns from Nojo-horem app I am unable to get the same colors on the RGB-Scart connection.

Please, check out an example image:

This is what I obtain from the RGB scart:
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

And this is how it looks on the component output:

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

Is there anything I should take in consideration?
Thank you

c0pperdragon, 2021-11-14:
Looking at your image is would say that the original blue channel is missing completely and the original red channel is fed into the output blue instead. This is true only if the blue text is really static.

c0pperdragon, 2021-11-14:
If the blue text is misleading, it could be just as well that red and blue are just crossed out.

rapiqui, 2021-11-14:
Thanks for your quick response.
I also thought the same initially, hence I tried to change the color channels connection to the scart, but this made some other weird color scheme that wasn't correct (red tinted).
Right now, testing with a multimeter, there is continuity from:

- Component blue RCA inner tip to scart pin 7
- Component red RCA inner tip to scart pin 15
- Component green RCA inner tip to scart pin 11

c0pperdragon, 2021-11-14:
Did you also connect all the relevant ground pins in the scart plug (5, 9, 13)? Leaving them floating could cause unexpected behaviour.
If yes, then the only thing I can imagine is a faulty scart input. Do you have a way to test this with another signal source?

rapiqui, 2021-11-14:
Hi,

Yes, ground pins are tied together and properly connected.
I have done a little bit more of testing and got some updates.
I connected the c64 with c64rgb mod on 240p switch position to an ossc instead of the lcd tv's scart and tried the AV1 with RGsB profile.  The OSSC displayed 312p, 15.63Khz and 50.10Hz, but no image was shown on the TV.
I switched then to 480p, the OSSC displayed 624p, 31.28Khz and 50.13Hz and the same incorrect color scheme appeared.
Finally I switched to AV1 YPbPr OSSC profile and then magic, the colors were perfectly displayed on the TV, so it seems that for some reason, even after having changed the palette to RGBns, the color signal is still being sent as YPbPr.

I did follow the instructions of nojo-horem's tool to change the palette, and after saving it, even power cycle the C64.

rapiqui, 2021-11-14:
Got it! It's currently working fine. Seems that the program could not upload the palette properly because I didn't switch the toggle to 480p before uploading the new palette. Once done I was able to power cycle down the C64 and connect it to the LCD tv via scart and using the switch 240p position the image colours are shown as they should. So, it was my fault.

Thank you anyway for your help and thanks for designing this beautiful piece of hardware.

Closed 2021-11-14.

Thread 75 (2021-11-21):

Troubleshooting help

mwardy1972, 2021-11-21:
I’ve had the component video mod from videogameperfection.com for a couple of months now and it's been working great ! But just the other day I turned on my c64 and the component output has stopped working.  The composite video output works fine. I just get a blank screen from the component output. Also, after a few moments the TV says ‘no signal’ when using the component output. I tried another tv in the house, same result. Unplugged the vic adapter board and ribbon cable, re-seated to be sure, still no go. A quick check with the multimeter, the voltage regs are putting out spot on 3.3V. I’m at a bit of a loss now trying to trouble shoot. I thought of getting a USB Blaster and trying to re-install the firmware ? Any ideas how to fix this ? Thankyou !

(my c64 board is 250469 Rev A and my VIC chip is 85652R2)

c0pperdragon, 2021-11-21:
If it suddenly stopped working this is probably a hardware fault. I don't think re-installing the firmware will do any good.
This now may sound stupid, but have you possibly changed the position of the output mode switch to a mode your TV can not display?

Now seriously: Troubleshooting the device without a means to see the signals is pretty impossible. As you have no oscilloscope we need to get creative here. You can use your working composite output image and super-impose any digital signal by coupling the signal into the analog video output.
Try this: Use as simple resistor with about 4.8K and feed the signal you wand to proble through this resistor into the junction point of R30,R31,R32 on the FPGA board. The best access to this point is at the side of R32 that is pointed towards the video amplifier AMP2.
To see if this rig works, start by probing pin 17 on the VIC-II itself, which is the system clock.  You should see very distinct horizontal stripes (4 pixels light, 4 pixesl dark) on your video display.

If this works, try probing all the signals that come trough the ribbon cable from the adapter board. All pins besides 15 and 16 should have at least some activity when in the C64 start screen.
Please report back then.

mwardy1972, 2021-11-27:
Hi ! thanks for the help, I really appreciate it.  So, using your guidance and a bit of troubleshooting myself, I have found that U2, the 3.3V voltage regulator on the VIC adapter board is not functioning.

As you suggested, I got a nice strong clock signal as you on pin 17.  But I didn't have anything on the ribbon cable at all.  I probed onto the VIC-II on the equivalent pins (i.e. DB0-DB11, A0-A5) and got the activity you described.  Which led me to review the schematic for the adapter board and I had missed this voltage regulator. I checked and found pin 5 had no voltage.  So to test it, I placed a bridge over to the output of REG 2, and ..... YES !! it works.  Found the problem, U2 is dead.  Now I just have to work out how to replace it, it is tiny.  Thankyou.

c0pperdragon, 2021-11-27:
My congratulations! Nice to hear that this impromptu oscilloscope actually worked.

The voltage regulator on the adapter board is indeed pretty tiny. If you don't mind a bit of a mess and the damaged regulator is not interfering otherwise, you could leave it in and just wire a larger regulator to the capacitors directly.

mwardy1972, 2021-12-07:
I've managed to do a fairly neat job using a MCP1700-3302E 3.3V regulator.  Working great.  Might be helpul if anyone else experiences this issue.
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

Closed 2022-02-11.

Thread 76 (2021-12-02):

Help with making a RGB SCART cable for Sony CRT TV

tyristori, 2021-12-02:
I'm trying to make a RGB SCART for my Sony KV29K5E. Here is the SCART connector on the TV from the service manual.

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

I've connected signals from TRRS to SCART. Red to pin 15, Green to pin 11 and Blue to pin 7. And respective grounds to pins 13, 9 and 5.

I've set the output to RGsB with the palette editor and manually set the TV to RGB mode.. TV doesn't see any signal coming in. Screen stays black.

I also tried to connect composite video signal from C64 video port to pin 20 and ground to pin 18. And set the output with palette editor to RGBns. It didn't make a difference.

Worth noting that I can't get even composite signal to work with SCART. It does work if I connect composite signal to composite input on the front of the TV.

RGB from my Amiga works fine so the SCART input on the TV is ok.

Any help would be appreciated.

c0pperdragon, 2021-12-03:
RGsB will of course not help you, so RGBns is the right choice here with using composite from the A/V port for sync. So far you seem to have done everything right. But to get at least any picture at all it is pretty irrelevant which colors you have programmed.

First thing is to solve the problem, that you can not get the original composite signal into your TV via the scart port. Without this, there is no sync signal and no hope the get any picture. For this test you need to revert the settings of your TV back to composite input (otherwise you may have some stable sync running, but the video may still be black).

Maybe you can even do an investigation on how your amiga cable is actually wired up.

tyristori, 2021-12-06:
Success!

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

The RGB enable signal was needed. Picture quality is amazing on this big Trinitron.

Now I need to make a cable that takes the power for RGB enable from C64 video port.

Icelvlan88, 2021-12-06:
Hello,

I got a custom component cable made but can you give a small guide on how you did this? Looking to use RGB instead of component.

On Dec 6, 2021, at 2:59 PM, tyristori ***@***.***> wrote:

Closed #76<https://github.com/c0pperdragon/C64-Video-Enhancement/issues/76>.

—
You are receiving this because you are subscribed to this thread.
Reply to this email directly, view it on GitHub<https://github.com/c0pperdragon/C64-Video-Enhancement/issues/76#event-5722993341>, or unsubscribe<https://github.com/notifications/unsubscribe-auth/APCADXNMXE35FCJUWJ4ENLTUPUIZ3ANCNFSM5JILEPRQ>.
Triage notifications on the go with GitHub Mobile for iOS<https://apps.apple.com/app/apple-store/id1477376905?ct=notification-email&mt=8&pt=524675> or Android<https://play.google.com/store/apps/details?id=com.github.android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>.

Closed 2021-12-06.

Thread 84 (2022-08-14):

Moving horizontal line issue on PAL.

zabykrinich, 2022-08-14:
Hi
I have got an issue on PAL c64. It looks like several pixels wide flickering line moves from top to bottom of the screen.
Also I have composite output black and white on the TV.

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

My board revision is 250425 rev A and MOS6069 VIC2.

I suspect it can be the clock issue (since composite is black and white color output).  Unfortunately on this board revision all clock components were replaced  to MOS 8701 clock generator chip. Probably there is a way just to remove this chip and apply "clock fix" or replace one of chip legs to R24 wire. Is there any way to apply and try the "clock fix" in my case? Did someone experienced the same issue as my one?
Unfortunately I can't tell which sw version I have. I suppose the latest on Jan 26, 2022.
I tried to install RF modulator back so no any issues are seen there.

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

zabykrinich, 2022-08-20:
I tried to scope pins and R24 output. As far as I understand the "clock fix" is to replace DOT clock signal to FPGA produced one.
Unfortunately I do not see any frequency on R24 resistor. I got constant voltage there.
I wonder if my unit is broken or may be software should be changed to enable it?

Imperious685, 2022-08-21:
The 6569 Vic II chip is a 12v and 5v part. I can see on the photo that Your Component Mod board has the jumper for 12v open where it should be shorted.  That should only be open if You have a 8565 Pal or 8565 Ntsc Vic II.
Just add a solder blob there and see if that fixes the problem.  I have and older Breadbin model with 6569 and a newer 64c with 6565 and have now modded both of them. I don't have that problem.

zabykrinich, 2022-08-22:
> Just add a solder blob there and see if that fixes the problem.

Thank you for your answer I need to read documentation more carefully.
I applied the jumper, but still nothing was changed. RGB out has pixel distortion, Composite has black and white but there is no such kind of distortion (only regular composite ones).  Also I do not see any clock signal on R24. So probably I need to check or update software version.
I tried to connect to composite TV, RGB tv,  commodore crt composite one and RGB, also thru retrotink so it seems the issue is not the screen one.

c0pperdragon, 2022-08-24:
The "clock fix" you mention is probably not what you need here. This issue is mainly with earlier boards that do not yet have the MOS 8701.  Anyway you would need a firmware update for the mod board, because the boards from videogameperfection.com do come with version 2.6 which do not yet provide the dot clock.

This moving area of noise on the screen very strongly hits at a problem with the power supply.  Other users have reported similar issues: https://github.com/c0pperdragon/C64-Video-Enhancement/issues/61

zabykrinich, 2022-08-24:
> This moving area of noise on the screen very strongly hits at a problem with the power supply.

Thank you I switched to original PSU  and the problem dissappeared. So it is definitely power supply. It is quite strange since custom PSU provides more current on 5v and 9v rails than original one.
I scoped clock pins with original and custom PSUs and saw some noise on custom one.

Thank you for investigation. It is good to know that my unit is working :-)

P.S. Be aware if you use following PSU with the unit.
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

c0pperdragon, 2022-08-24:
Even if this is now working, I strongly advice against using the original PSU any longer. It is common wisdom, that these may destroy your machine when their voltage regulator eventually fails.

zabykrinich, 2022-08-24:
> Even if this is now working, I strongly advice against using the original PSU any longer. It is common wisdom, that these may destroy your machine when their voltage regulator eventually fails.

Sure I will try different PSUs from the market and add link to working one in this thread.

Closed 2022-08-24.

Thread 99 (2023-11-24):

Rev. 6 died after flashing v2.11

shindouj, 2023-11-24:
Hi there,

I have finished assembling my Rev. 6 C64 Video Enhancement yesterday and got to the point of it working with the test firmware - got perfect gradients and a stable signal - so I decided it is okay to go ahead and flash the final firmware onto the FPGA.

Right away after programming the chip the JTAG stopped working (Quartus complains about JTAG chain - like the chip was not there). There was no component signal either. I have assembled and plugged the daughterboard in since then and it did not change (no signal, no JTAG). However, the analog part is working - I am still getting composite output.

Do you have an idea what might be the issue here? I think nobody here had a similar issue, at least it's not something I have found while browsing through issues...

Thanks a lot for your support.

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

c0pperdragon, 2023-11-24:
Flashing the firmware has serious challenges.  Maybe something in these threads may help you:
https://github.com/c0pperdragon/C64-Video-Enhancement/issues/80
https://github.com/c0pperdragon/C64-Video-Enhancement/issues/97

shindouj, 2023-11-24:
Thanks, but I think we misunderstood each other.

I have successfully flashed the firmware already - quite a few times, actually. Right after building the board I have flashed [the pattern generator](https://github.com/c0pperdragon/A-VideoBoard/releases/tag/1.1) at least three times. My USB blaster is detected just fine, and I used Prime 18.1 as suggested. That step worked flawlessly, and after flashing the firmware, a pattern has been generated.

However, after _successfully_ (according to Prime) flashing the [video enhancement 2.11 firmware](https://github.com/c0pperdragon/C64-Video-Enhancement/releases/tag/2.11) made the board essentially dead, with the JTAG header apparently not working anymore - something that did not happen with the pattern generator firmware. This has happened immediately after flashing - when flashing was completed at 100%, I opened the programmer again, and it was not able to recognize the chip anymore.

I don't think this is an issue with my blaster or my programming setup since that has succeeded before (and by before, I mean 12 hours ago - when flashing the pattern generator).

c0pperdragon, 2023-11-24:
The real firmware (in contrast to the pattern generator) shares the JTAG pins for some functionality. So it may very well be that this is now conficting with the programmer to prevent further access to it. Using the software and hardware mentioned in the other threads on this topic seems to overcome this problem somehow.

shindouj, 2023-11-24:
Oh, understood. That may be very well the case. Well - I'm off to doing a proper fix for that trace, and thanks for your hard work on the mod! I'm impressed I managed to make it work at all, it was my second time doing any SMD soldering at all 😅

c0pperdragon, 2023-11-24:
Wow! Going from 0 to 144 pin, 0.5mm is a pretty steep learning courve.

Closed 2023-11-24.

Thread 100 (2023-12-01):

C64 into Framemeister Cable

a7mag3ddon, 2023-12-01:
Hi, is there a standard way to connect the C64 using the TRSS jack to the Framemeister or do i need to purchase a D Terminal to YPbPr cable? These cables are hard to get in UK or expensive to order in. I was using the OSSC for a while but now i have a framemeister thought id try and get it working on 1 device instead of having 2.

Just wanted to check before buying anything.

c0pperdragon, 2023-12-01:
I have no experience with the Framemeister. Reading the docs, it will accept component video only on the D terminal.
But you could reprogramm the C64 mod to output RGB directly. Using the composite signal and the audio from the original A/V port and you can actually get all signals needed for SCART for which you may already have some adapter.

When soldering things yourself is not an option, you will need to go with the mentioned D Terminal to YPrPr cable,

a7mag3ddon, 2023-12-19:
I have bought the D terminal plug but im not getting a picture, the D terminal has a ref, blue and gree phono on it and i connected it to the red, green and blue phono on the TRSS jack which i assume is ok.

Is the there a digram to tell me which phono is what signal out of the C64 TRSS to make sure they match ?

c0pperdragon, 2023-12-19:
The composite signal from the A/V connect would only be needed as sync, not as the actual color lines. The color would come from the mod. So the quality with RGB would be just as good with component. You will need to reprogram the palette of the mod using the palette editing tool: https://github.com/Hojo-Norem/c0pperdragon-VIC-II-Palette-editor

a7mag3ddon, 2023-12-20:
I've just tested my framemeister component port using a pS2 and D cable and that works so it would seem logical that it's the D port that's either not wired correctly or has a problem.

Please can you tell me what signals are coming out the R, G and Blue Phonos from the TRSS jack so I can test with my multimeter that the correct wiring is going to the correct pins on the D terminal ?

Think I'm getting close to it working now.

Thanks

a7mag3ddon, 2023-12-20:
Another update, ive back traced the wiring from the componenet cable i bought and the G, B and Red phonos all go to the correct pins of the D Terminal so not sure where to go now.

a7mag3ddon, 2023-12-20:
Closed this issue, was the switch on the rear, i needed to move it accross one!

Closed 2023-12-20.

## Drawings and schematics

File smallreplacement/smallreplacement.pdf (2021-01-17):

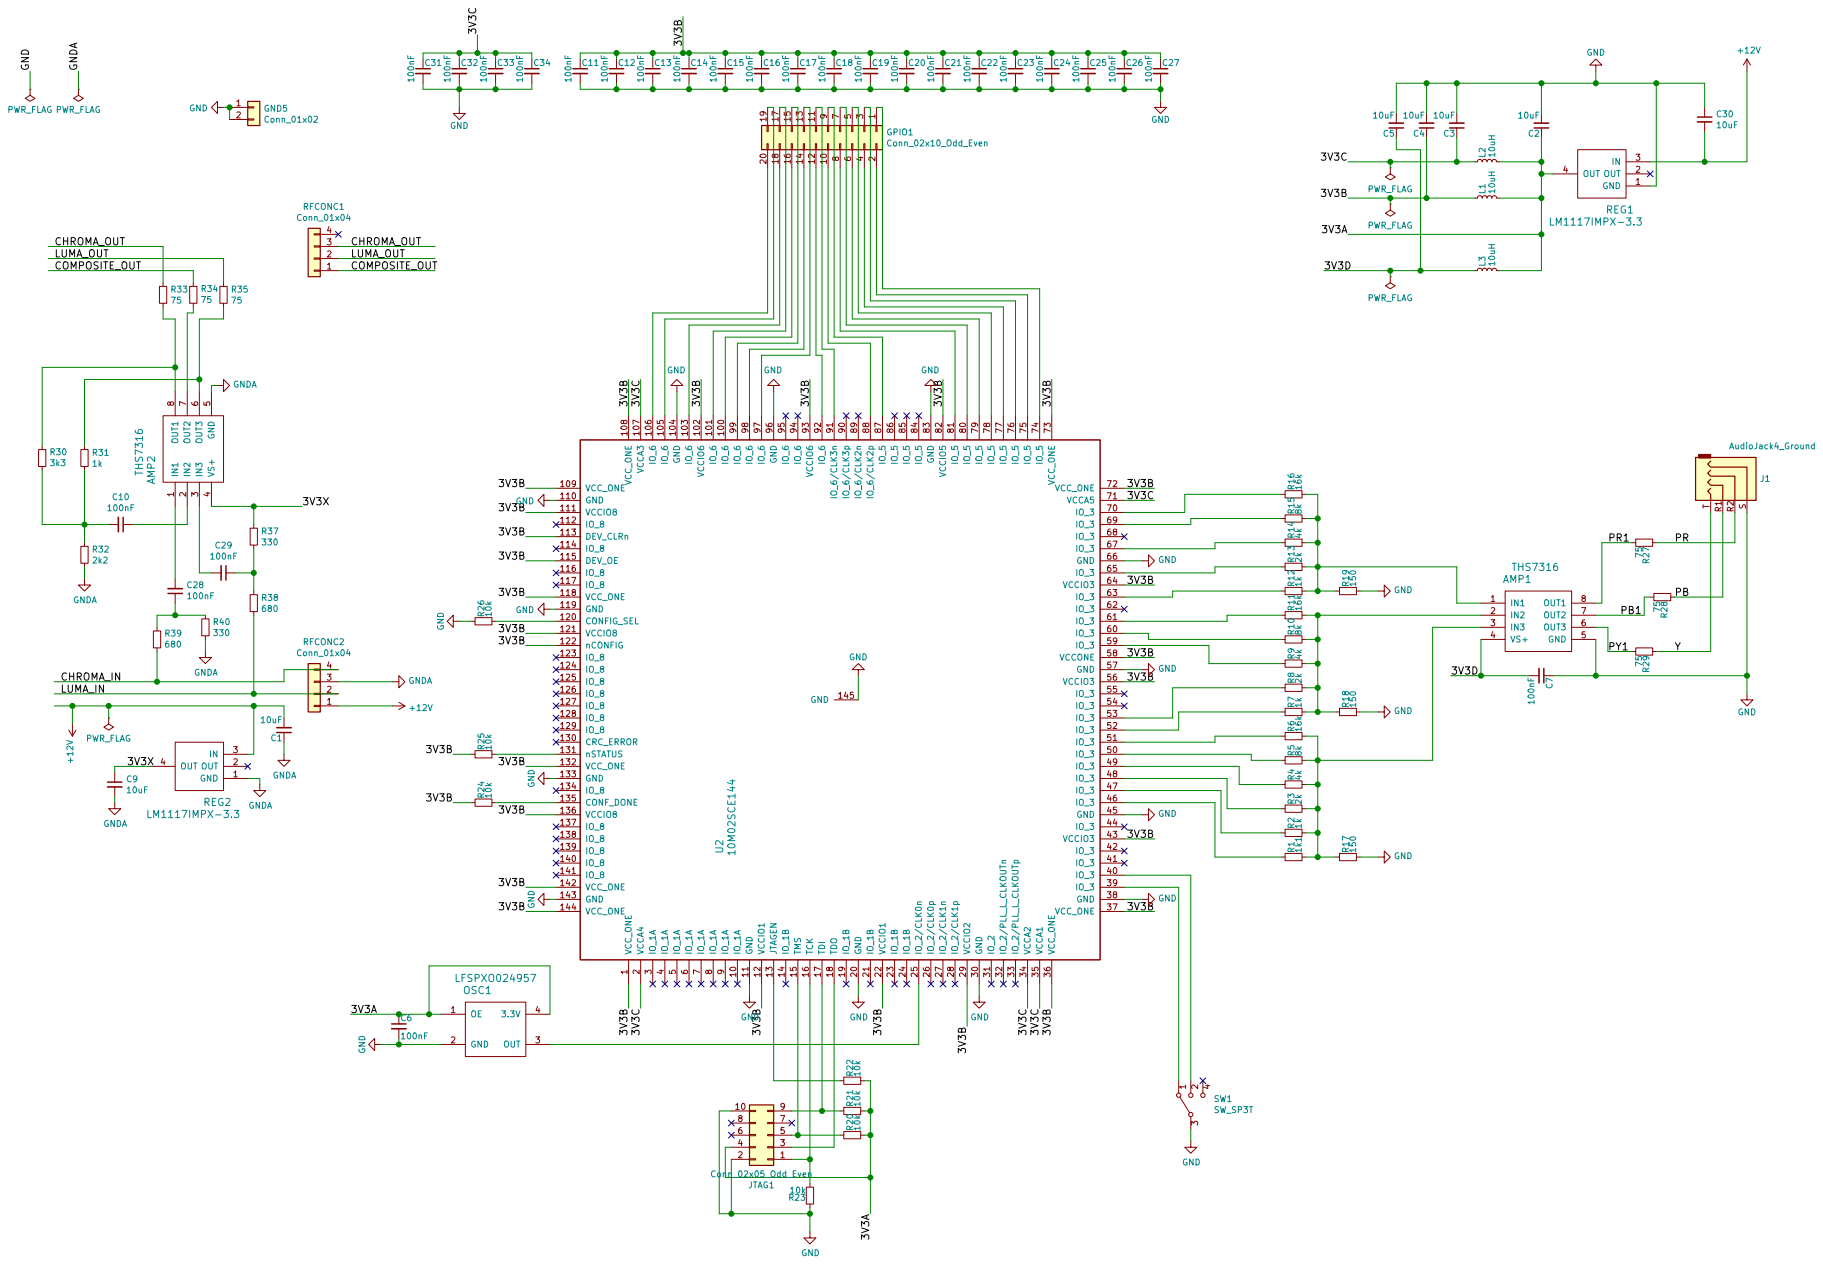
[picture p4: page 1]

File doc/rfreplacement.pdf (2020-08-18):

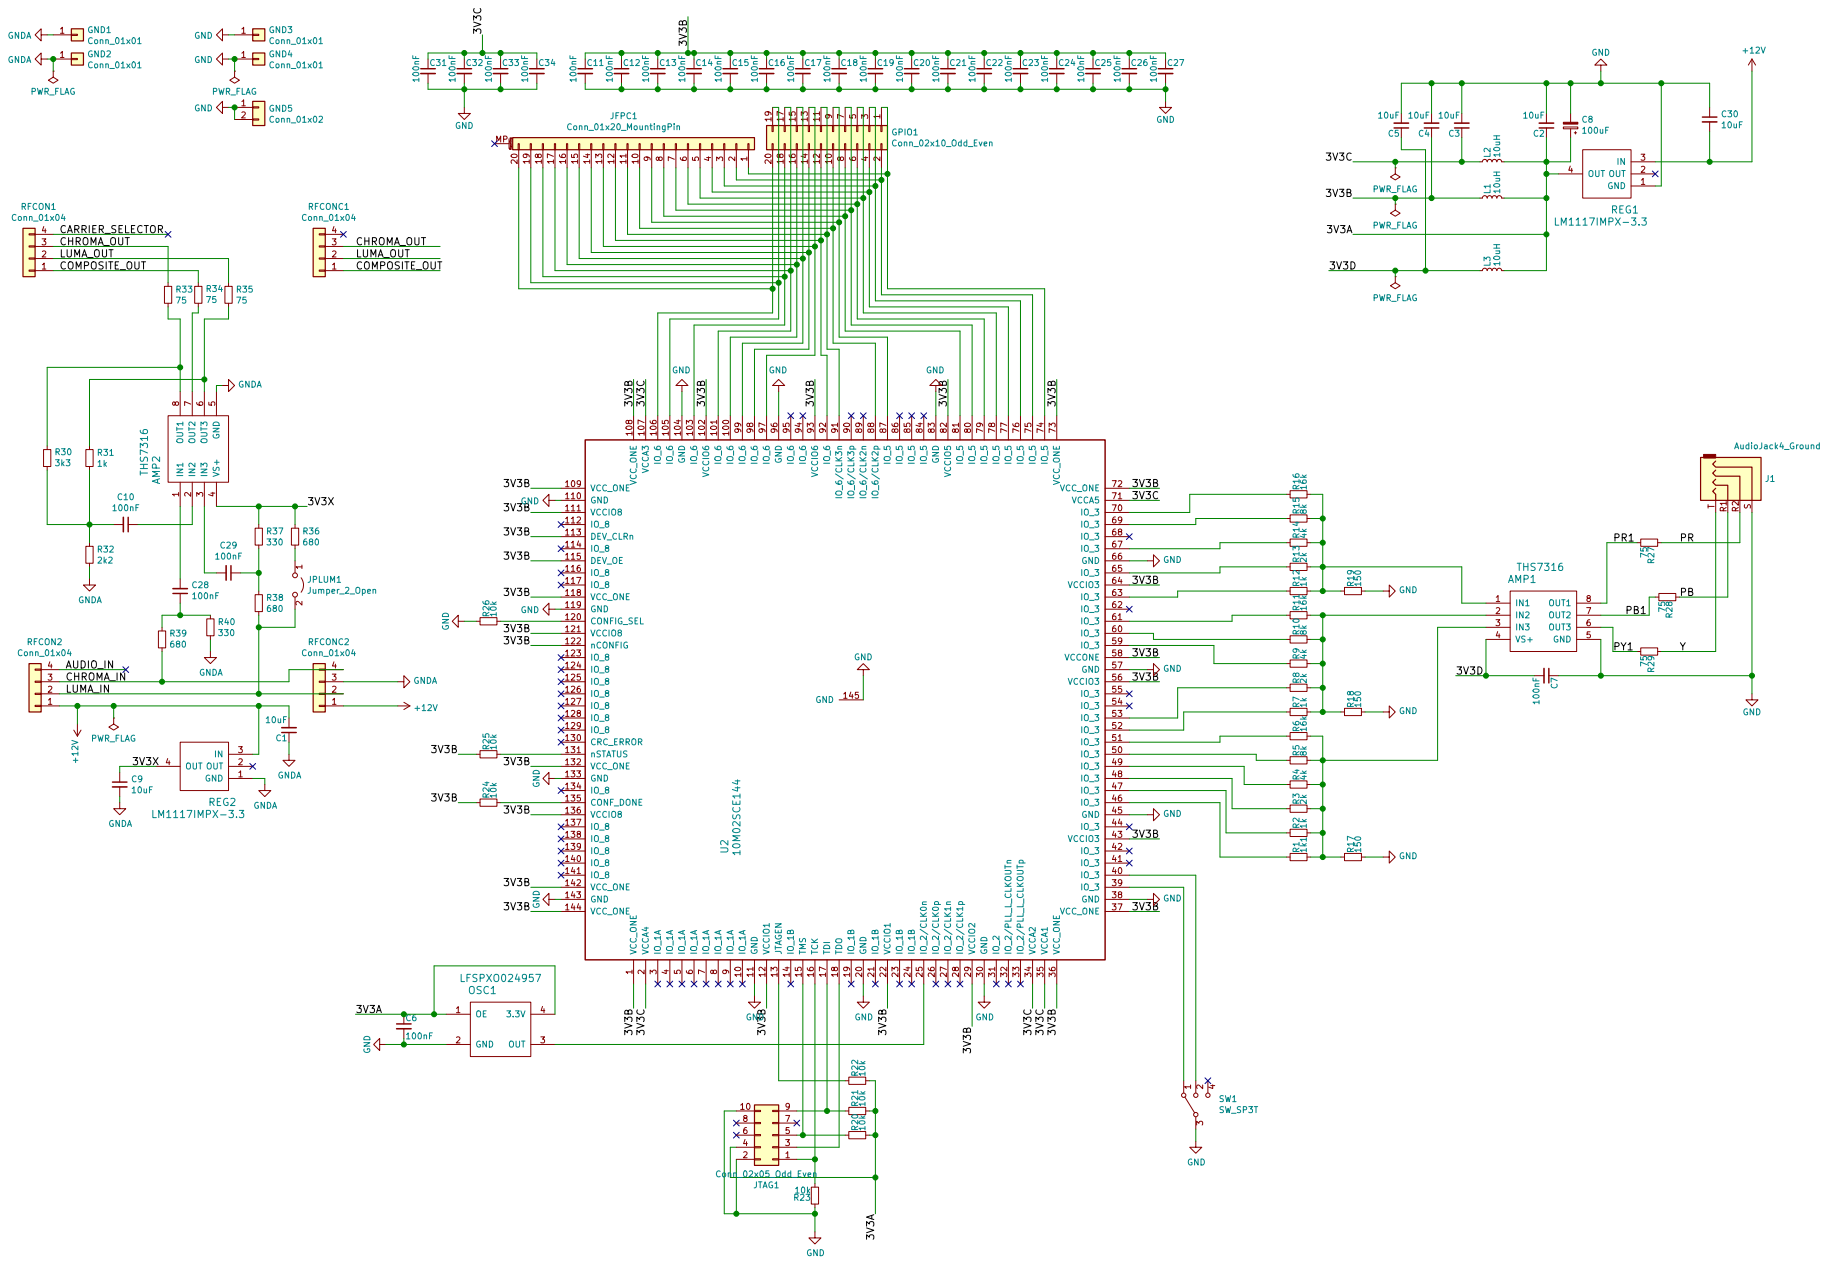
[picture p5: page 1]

CHROMA_IN 3
1 | 2 1

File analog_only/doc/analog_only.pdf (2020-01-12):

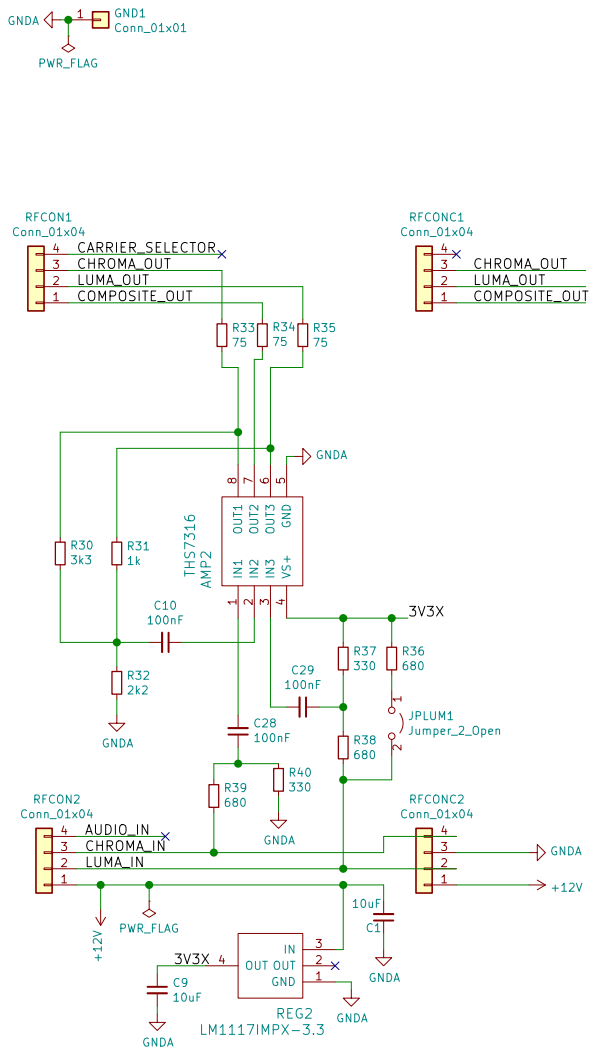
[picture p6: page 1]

github.com/c0pperdragon/A-VideoBoard
File: rfreplacement.sch Sheet: / c0pperdragon

Id: 1/1 Title: RF replacement, analog only

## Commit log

2019-01-27 Initial check-in
    [rfreplacement-2018-12-04-19-31-54.sch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]
2019-03-10 Board Rev. 3
    Fixed the order of the video signal pins: Switch Y and Pr to make it conform to the de-factor standard for component video on TSSR.
    Tidy up the silk screen a bit.
    [rfreplacement-B.Cu.gbr, rfreplacement-B.Mask.gbr, rfreplacement-B.SilkS.gbr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]
2019-08-14 BOM, restructure docu
    [fpgaboard_bom.ods]
2019-08-15 Move gerber files to documentation folder
2019-08-25 Rev. 4 of the PCB
    Moved the 2 "lonely" capacitors from the backside to the front.
    Rearranged silk screen a bit to avoid overlapping with drill holes and solder pads.
    [rfreplacement-B.Cu.gbr, rfreplacement-B.Mask.gbr, rfreplacement-B.SilkS.gbr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]
2019-12-09 Small analog-only version of the board
    [rfreplacement.kicad_pcb, rfreplacement.sch]
2019-12-10 Tidy up layout a bit
    [rfreplacement.kicad_pcb]
2020-01-12 Add BOM and schematics for analog-only board
    [analog_only.ods]
2020-04-14 Wire up testing harness
2020-04-14 Add FPGA pin assignment
2020-04-15 Test signal generator wiring and firmware
2020-04-20 Fixed mixed up capacitor designators on the analog only board.
    [rfreplacement.kicad_pcb]
2020-04-20 Fix board side specification in the BOM
    [fpgaboard_bom.ods]
2020-05-15 Add heat sink area to regulator. More space around adapter board connector.
    [rfreplacement-B.Cu.gbr, rfreplacement-B.Mask.gbr, rfreplacement-B.SilkS.gbr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]
2020-08-18 Add optional header for a flat-flex cable that may be used instead of the ribbon cable.
    [_saved_rfreplacement.sch, rfreplacement.kicad_pcb, rfreplacement.sch]
2020-08-18 Add optional header for flat-flex cable
    [_saved_rfreplacement.sch, rfreplacement.sch]
2021-01-17 Smaller version of the RF Replacment board
    [smallreplacement.kicad_pcb, smallreplacement.sch]
2021-01-23 Shink down the board a tiny bit more
    [smallreplacement.kicad_pcb]
2021-03-20 Pin assignments for testing with VIC-IIe adapter
2023-05-11 Adjust signal timing of test circuit
2023-06-22 Update KiCAD project structure
2023-09-06 Patch non-functional output pin to other pin
